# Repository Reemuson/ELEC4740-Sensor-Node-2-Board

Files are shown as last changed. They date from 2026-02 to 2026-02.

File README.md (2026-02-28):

<p align="center" width="100%">
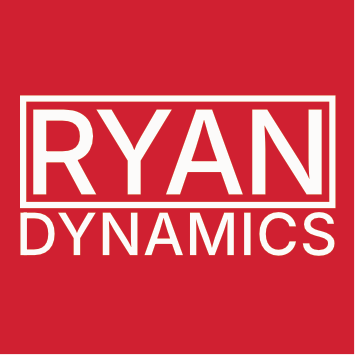
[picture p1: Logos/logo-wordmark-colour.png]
  
</p>

<h1 align="center">SN2 BREAKOUT BOARD</h1>

<p align="center" width="100%">
  <a href="https://github.com/Reemuson/ELEC4740-Sensor-Node-2-Board/actions/workflows/ci.yaml">
    
  </a>
</p>

<p align="center" width="100%">
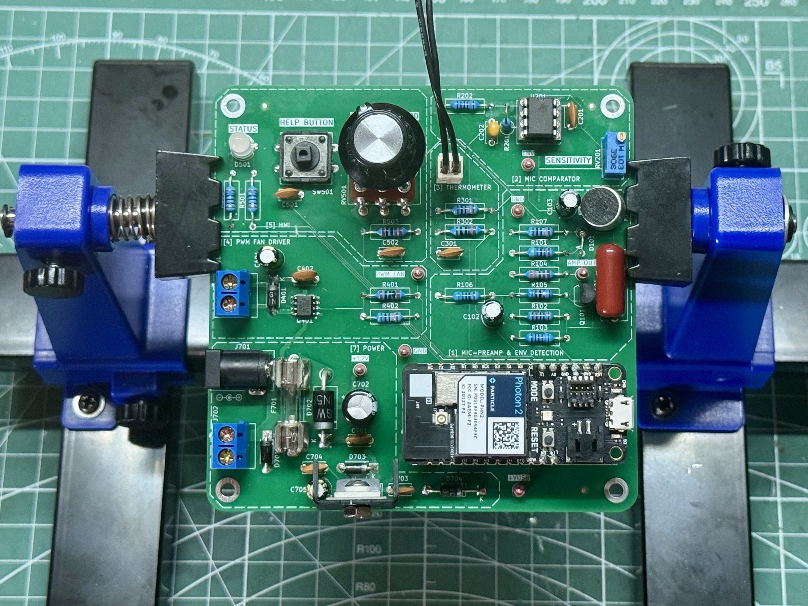
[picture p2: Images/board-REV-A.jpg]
    
</p>

***

<p align="center">
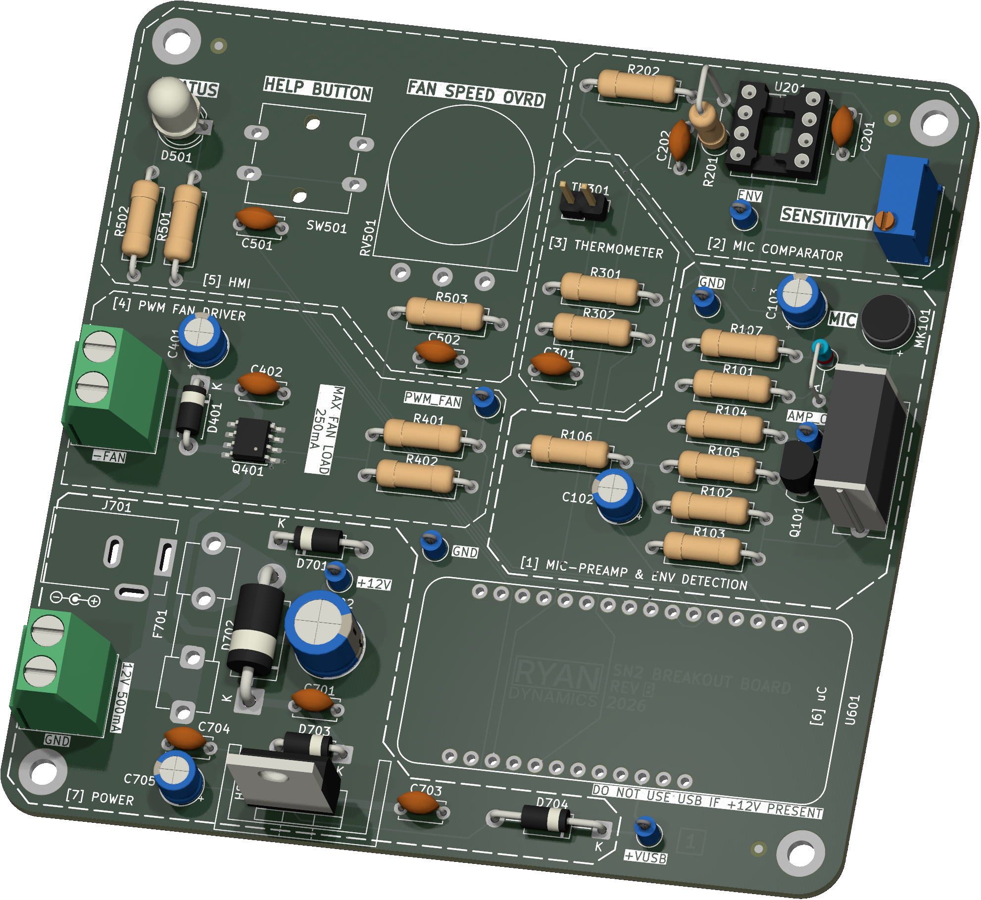
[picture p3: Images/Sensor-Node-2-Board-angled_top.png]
3D Top Angled
  
&nbsp; &nbsp; &nbsp; &nbsp;
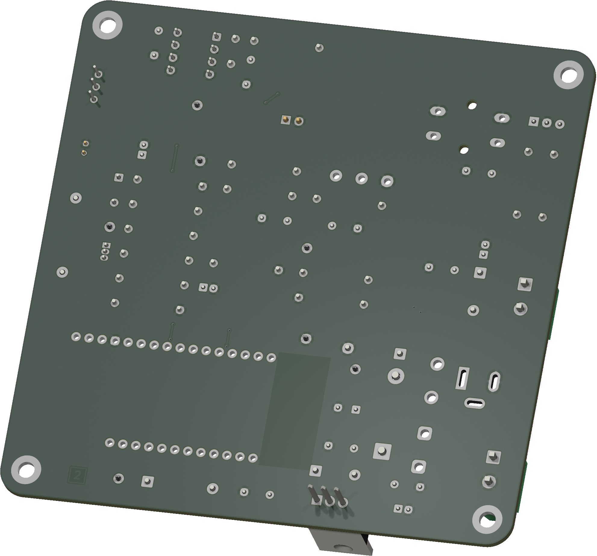
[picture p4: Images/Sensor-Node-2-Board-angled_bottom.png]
3D Bottom Angled
  
</p>

***

## SPECIFICATIONS

| Parameter | Value | 
| --- | --- |
| Dimensions | 100.0 × 100.0 mm |

***

## DIRECTORY STRUCTURE

    .
    ├─ Computations       # Misc calculations
    ├─ HTML               # HTML files for generated webpage
    ├─ Images             # Pictures and renders
    │
    ├─ kibot_resources    # External resources for KiBot
    │  ├─ colors          # Color theme for KiCad
    │  ├─ fonts           # Fonts used in the project
    │  ├─ scripts         # External scripts used with KiBot
    │  └─ templates       # Templates for KiBot generated reports
    │
    ├─ kibot_yaml         # KiBot YAML config files
    ├─ KiRI               # KiRI (PCB diff viewer) files
    │
    ├─ lib                # KiCad footprint and symbol libraries
    │  ├─ 3d_models       # Component 3D models
    │  ├─ lib_fp          # Footprint libraries
    │  └─ lib_sym         # Symbol libraries
    │
    ├─ Logos              # Logos
    │
    ├─ Manufacturing      # Assembly and fabrication documents
    │  ├─ Assembly        # Assembly documents (BoM, pos, notes)
    │  │
    │  └─ Fabrication     # Fabrication documents (ZIP, notes)
    │     ├─ Drill Tables # CSV drill tables
    │     └─ Gerbers      # Gerbers
    │
    ├─ Report             # Reports for ERC/DRC
    ├─ Schematic          # PDF of schematic
    ├─ Templates          # Title block templates
    ├─ Testing
    │  └─ Testpoints      # Testpoints tables      
    │
    └─ Variants           # Outputs for assembly variants

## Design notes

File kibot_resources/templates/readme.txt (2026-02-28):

<p align="center" width="100%">
  
</p>

<h1 align="center">${BOARD_NAME}</h1>

<p align="center" width="100%">
  <a href="${GIT_URL}/actions/workflows/ci.yaml">
    CI Badge
  </a>
</p>

<p align="center" width="100%">
    
</p>

***

<p align="center">
  3D Top Angled
&nbsp; &nbsp; &nbsp; &nbsp;
  3D Bottom Angled
</p>

***

## SPECIFICATIONS

| Parameter | Value | 
| --- | --- |
| Dimensions | ${bb_w_mm} × ${bb_h_mm} mm |

***

## DIRECTORY STRUCTURE

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

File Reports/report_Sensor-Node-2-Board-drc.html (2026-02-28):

Logo

(https://github.com/INTI-CMNB/KiBot/) | DRC report for Sensor-Node-2-Board
| PCB: Sensor-Node-2-Board Revision: 1.1.0+ (Unreleased) Date: 2026-02-28T02:42:13+0000 KiCad Version: 9.0.7 | Errors: 7 Warnings: 26 Total: 33

Violations

Type | Description | Details
items_not_allowed | Items not allowed (keepout area) | @(204.56 mm, 174.0 mm): PTH pad 1 [+12V] of D703
clearance | Clearance violation (netclass 'GND' clearance 0.2000 mm; actual 0.0000 mm) | @(225.99 mm, 151.25 mm): Via [/SCHEMATIC/GPIO_SOUND] on L1 (Sig, PWR) - L2 (Sig, GND) @(165.0 mm, 85.0 mm): Zone [GND] on L2 (Sig, GND), priority 3
hole_clearance | Hole clearance violation (board setup constraints hole clearance 0.2540 mm; actual 0.0905 mm) | @(225.99 mm, 151.25 mm): Via [/SCHEMATIC/GPIO_SOUND] on L1 (Sig, PWR) - L2 (Sig, GND) @(165.0 mm, 85.0 mm): Zone [GND] on L2 (Sig, GND), priority 3
clearance | Clearance violation (rule 'Minimum Trace Width and Spacing (outer layer)' clearance 0.2000 mm; actual 0.1405 mm) | @(225.99 mm, 148.01 mm): Track [/SCHEMATIC/GPIO_SOUND] on L2 (Sig, GND), length 3.2400 mm @(165.0 mm, 85.0 mm): Zone [GND] on L2 (Sig, GND), priority 3
clearance | Clearance violation (rule 'Minimum Trace Width and Spacing (outer layer)' clearance 0.2000 mm; actual 0.1505 mm) | @(226.0 mm, 151.0 mm): Track [/SCHEMATIC/GPIO_SOUND] on L2 (Sig, GND), length 0.2400 mm @(165.0 mm, 85.0 mm): Zone [GND] on L2 (Sig, GND), priority 3
clearance | Clearance violation (rule 'Minimum Trace Width and Spacing (outer layer)' clearance 0.2000 mm; actual 0.1405 mm) | @(226.0 mm, 151.24 mm): Track [/SCHEMATIC/GPIO_SOUND] on L2 (Sig, GND), length 0.0141 mm @(165.0 mm, 85.0 mm): Zone [GND] on L2 (Sig, GND), priority 3
lib_footprint_mismatch | Footprint 'C_Disc_D5.0mm_W2.5mm_P5.00mm' does not match copy in library 'Capacitor_THT'. | @(218.7 mm, 125.0 mm): Footprint C301
lib_footprint_mismatch | Footprint 'C_Disc_D5.0mm_W2.5mm_P5.00mm' does not match copy in library 'Capacitor_THT'. | @(205.0 mm, 125.0 mm): Footprint C502
lib_footprint_mismatch | Footprint 'C_Disc_D5.0mm_W2.5mm_P5.00mm' does not match copy in library 'Capacitor_THT'. | @(217.5 mm, 179.75 mm): Footprint C703
lib_footprint_mismatch | Footprint 'C_Disc_D5.0mm_W2.5mm_P5.00mm' does not match copy in library 'Capacitor_THT'. | @(184.0 mm, 175.0 mm): Footprint C704
lib_footprint_mismatch | Footprint 'D_DO-201AD_P15.24mm_Horizontal' does not match copy in library 'Diode_THT'. | @(192.5 mm, 168.74 mm): Footprint D702
lib_footprint_mismatch | Footprint 'PHOTON2' does not match copy in library 'Photon2'. | @(210.67 mm, 151.23 mm): Footprint U601
lib_footprint_mismatch | Footprint 'Potentiometer_Bourns_3296W_Vertical' does not match copy in library 'Potentiometer_THT'. | @(260.0 mm, 105.04 mm): Footprint RV201
lib_footprint_mismatch | Footprint 'CP_Radial_D5.0mm_P2.00mm' does not match copy in library 'Capacitor_THT'. | @(187.455112 mm, 179.75 mm): Footprint C705
lib_footprint_mismatch | Footprint 'Potentiometer_Omeg_PC16BU_Vertical' does not match copy in library 'Potentiometer_THT'. | @(211.0 mm, 115.0 mm): Footprint RV501
lib_footprint_mismatch | Footprint 'SW_SPST_Omron_B3F-40xx' does not match copy in library 'Button_Switch_THT'. | @(193.75 mm, 105.0 mm): Footprint SW501
lib_footprint_mismatch | Footprint 'TerminalBlock_Phoenix_MKDS-1,5-2_1x02_P5.00mm_Horizontal' does not match copy in library 'TerminalBlock_Phoenix'. | @(171.0 mm, 132.5 mm): Footprint J401
lib_footprint_mismatch | Footprint 'C_Disc_D5.0mm_W2.5mm_P5.00mm' does not match copy in library 'Capacitor_THT'. | @(203.0 mm, 168.74 mm): Footprint C701
lib_footprint_mismatch | Footprint 'SO-8_3.9x4.9mm_P1.27mm' does not match copy in library 'Package_SO'. | @(187.5 mm, 137.5 mm): Footprint Q401
lib_footprint_mismatch | Footprint 'CP_Radial_D5.0mm_P2.00mm' does not match copy in library 'Capacitor_THT'. | @(232.5 mm, 140.0 mm): Footprint C102
lib_footprint_mismatch | Footprint 'LED_D5.0mm-3' does not match copy in library 'LED_THT'. | @(175.04 mm, 100.0 mm): Footprint D501
lib_footprint_mismatch | Footprint 'CP_Radial_D5.0mm_P2.00mm' does not match copy in library 'Capacitor_THT'. | @(180.0 mm, 127.5 mm): Footprint C401
lib_footprint_mismatch | Footprint 'D_DO-41_SOD81_P12.70mm_Horizontal' does not match copy in library 'Diode_THT'. | @(236.35 mm, 179.75 mm): Footprint D704
lib_footprint_mismatch | Footprint 'C_Disc_D5.0mm_W2.5mm_P5.00mm' does not match copy in library 'Capacitor_THT'. | @(185.0 mm, 131.19 mm): Footprint C402
lib_footprint_mismatch | Footprint 'C_Disc_D5.0mm_W2.5mm_P5.00mm' does not match copy in library 'Capacitor_THT'. | @(250.0 mm, 90.0 mm): Footprint C201
lib_footprint_mismatch | Footprint 'DIP-8_W7.62mm_Socket' does not match copy in library 'Package_DIP'. | @(238.69 mm, 90.0 mm): Footprint U201
lib_footprint_mismatch | Footprint 'TO-220-3_Vertical' does not match copy in library 'Package_TO_SOT_THT'. | @(203.29 mm, 179.75 mm): Footprint U701
lib_footprint_mismatch | Footprint 'PinHeader_1x02_P2.54mm_Vertical' does not match copy in library 'Connector_PinHeader_2.54mm'. | @(222.54 mm, 105.0 mm): Footprint TH301
lib_footprint_mismatch | Footprint 'C_Disc_D5.0mm_W2.5mm_P5.00mm' does not match copy in library 'Capacitor_THT'. | @(231.35 mm, 93.81 mm): Footprint C202
lib_footprint_mismatch | Footprint 'CP_Radial_D5.0mm_P2.00mm' does not match copy in library 'Capacitor_THT'. | @(248.85 mm, 115.0 mm): Footprint C103
lib_footprint_mismatch | Footprint 'TerminalBlock_Phoenix_MKDS-1,5-2_1x02_P5.00mm_Horizontal' does not match copy in library 'TerminalBlock_Phoenix'. | @(171.0 mm, 167.5 mm): Footprint J702
lib_footprint_mismatch | Footprint 'C_Disc_D5.0mm_W2.5mm_P5.00mm' does not match copy in library 'Capacitor_THT'. | @(181.25 mm, 111.25 mm): Footprint C501

Unconnected items

Type | Description | Details
unconnected_items | Missing connection between items | @(184.25 mm, 148.75 mm): Zone [/SCHEMATIC/+12V_FUSED] on L1 (Sig, PWR), priority 2 @(192.5 mm, 149.0 mm): PTH pad 1 [/SCHEMATIC/+12V_FUSED] of D701

Generated by KiBot (https://github.com/INTI-CMNB/KiBot/) v1.8.6

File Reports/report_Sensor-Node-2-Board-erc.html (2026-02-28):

Logo

(https://github.com/INTI-CMNB/KiBot/) | ERC report for Sensor-Node-2-Board
| Schematic: Sensor-Node-2-Board Revision: 1.1.0+ (Unreleased) Date: 2026-02-28T02:42:11+0000 KiCad Version: 9.0.7 | Errors: 0 Warnings: 12 Total: 12

Sheet / (Sensor-Node-2-Board.kicad_sch)

Type | Description | Details
lib_symbol_mismatch | Symbol 'BC549' doesn't match copy in library 'Transistor_BJT' | @(1.3335 mm, 0.6985 mm): Symbol Q101 [BC549]
footprint_link_issues | The current configuration does not include the footprint library 'RD-Testpoints'. | @(1.4605 mm, 0.5461 mm): Symbol TP101 [TestPoint]
lib_symbol_mismatch | Symbol 'Thermistor_NTC' doesn't match copy in library 'Device' | @(0.762 mm, 1.4097 mm): Symbol TH301 [Thermistor_NTC]
footprint_link_issues | The current configuration does not include the footprint library 'RD-Testpoints'. | @(1.3716 mm, 1.27 mm): Symbol TP401 [TestPoint]
footprint_link_issues | The current configuration does not include the footprint library 'RD-Testpoints'. | @(1.3716 mm, 1.778 mm): Symbol TP901 [TestPoint]
footprint_link_issues | The current configuration does not include the footprint library 'RD-Testpoints'. | @(1.3716 mm, 1.9558 mm): Symbol TP902 [TestPoint]
footprint_link_issues | The current configuration does not include the footprint library 'RD-Testpoints'. | @(2.5146 mm, 0.5461 mm): Symbol TP201 [TestPoint]
footprint_link_issues | The current configuration does not include the footprint library 'RD-Symbols-Silkscreen'. | @(1.7526 mm, 1.9431 mm): Symbol ID901 [BOARD_STACKUP_MARKER]
lib_symbol_issues | The current configuration does not include the symbol library 'Ryan-Dynamics' | @(1.7526 mm, 1.9431 mm): Symbol ID901 [BOARD_STACKUP_MARKER]
footprint_link_issues | The current configuration does not include the footprint library 'RD-Testpoints'. | @(2.54 mm, 1.8161 mm): Symbol TP702 [TestPoint]
footprint_link_issues | The current configuration does not include the footprint library 'RD-Heatsinks'. | @(2.9845 mm, 1.7653 mm): Symbol HS701 [Heatsink]
footprint_link_issues | The current configuration does not include the footprint library 'RD-Testpoints'. | @(3.2004 mm, 1.778 mm): Symbol TP701 [TestPoint]

Generated by KiBot (https://github.com/INTI-CMNB/KiBot/) v1.8.6

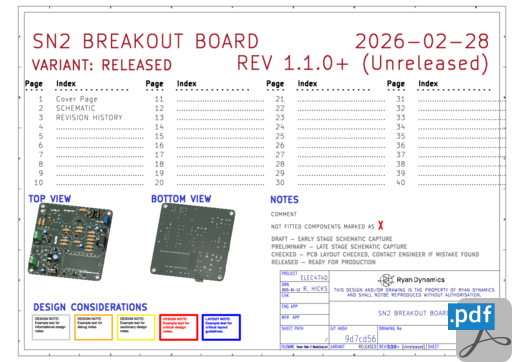
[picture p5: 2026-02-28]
HTML/images/cat_pdf_schematic_Sensor-Node-2-Board-schematic.png

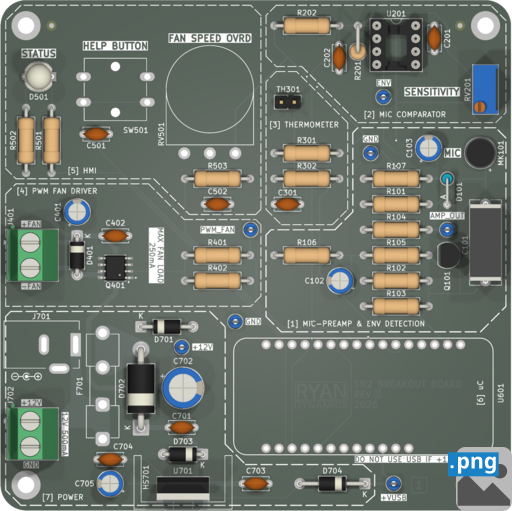
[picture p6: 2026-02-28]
HTML/images/cat_png_3d_viewer_top_Sensor-Node-2-Board-top.png

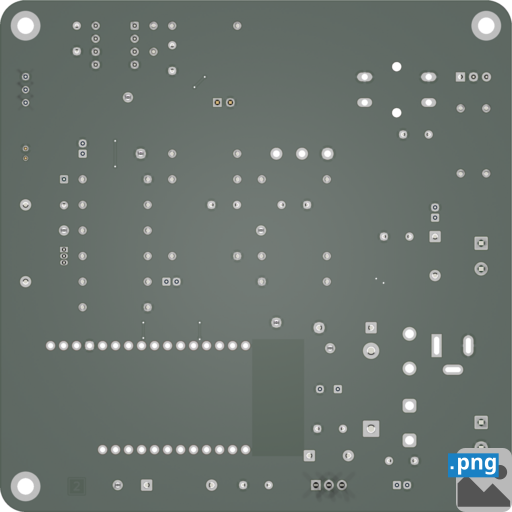
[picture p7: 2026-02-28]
HTML/images/cat_png_3d_viewer_bottom_Sensor-Node-2-Board-bottom.png

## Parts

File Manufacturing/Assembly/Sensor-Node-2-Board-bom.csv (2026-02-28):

Row | Quantity Per PCB | References | Value | Datasheet | Footprint | Description | Tolerance | Voltage | Manufacturer | MPN | Supplier | SPN | Notes
1 | 8 | C201 C301 C402 C501 C502 C701 C703 C704 | 100n | ~ | C_Disc_D5.0mm_W2.5mm_P5.00mm | CAP CER Y5U 100N 50V 20% P=5MM | 20% | 50V |  |  | Jaycar Electronics | RC5360
2 | 2 | C101 C202 | 1u | ~ | C_Rect_L16.5mm_W6.0mm_P15.00mm_MKT | CAP GRN 1U 100V P=11MM CAP MONO 1U 50V |  | 100V 50V |  |  | Jaycar Electronics | RG5170
3 | 2 | C102 C103 | 3.3u | ~ | CP_Radial_D5.0mm_P2.00mm | CAP LL CD81 RB 3U3 50V P=2MM 5X11MM | 10% | 50V |  |  | Jaycar Electronics | RL6422
4 | 2 | C401 C705 | 10u | ~ | CP_Radial_D5.0mm_P2.00mm | Polarized capacitor |  | 25V
5 | 1 | C702 | 47u | ~ | CP_Radial_D8.0mm_P3.50mm | Polarized capacitor |  | 25V
6 | 1 | D703 | 1N4004 | http://www.vishay.com/docs/88503/1n4001.pdf | D_DO-41_SOD81_P7.62mm_Horizontal | 400V 1A General Purpose Rectifier Diode, DO-41
7 | 1 | D101 | 1N4148 | https://assets.nexperia.com/documents/data-sheet/1N4148_1N4448.pdf | D_DO-35_SOD27_P5.08mm_Vertical_AnodeUp | DIODE 1N4148 FAST 100V 250MA DO41 |  |  |  |  | Jaycar Electronics
8 | 2 | D401 D704 | 1N5819 | http://www.vishay.com/docs/88525/1n5817.pdf | D_DO-41_SOD81_P7.62mm_Horizontal | DIODE 1N5819 SCHOTTKY 40V 1A DO41 |  |  |  |  | Jaycar Electronics | ZR1020
9 | 1 | D702 | 1N5822 | http://www.vishay.com/docs/88526/1n5820.pdf | D_DO-201AD_P15.24mm_Horizontal | DIODE 1N5822 SCHOTTKY 40V 3A DO41 |  |  |  |  | Jaycar Electronics | ZR1023
10 | 1 | D501 | LED_STATUS | ~ | LED_D5.0mm-3 | LED 5MM DIF BICOL COM CATH ORG/GRN 70/80 |  |  |  |  | Jaycar Electronics | ZD0252
11 | 1 | D701 | P4KE16 | ~ | D_DO-41_SOD81_P10.16mm_Horizontal | DIODE TVS UNIDIRECTIONAL
12 | 1 | F701 | 500mA M205 | ~ | Fuseholder_Clip-5x20mm_Eaton_1A5601-01_Inline_P20.80x6.76mm_D1.70mm_Horizontal | Fuse
13 | 1 | HS701 | Heatsink | ~ | Heatsink_6073B_19x9.5mm | Heatsink
14 | 3 | J401 J701 J702 | EBWA-02-B | ~ | TerminalBlock_Phoenix_MKDS-1,5-2_1x02_P5.00mm_Horizontal | TERMINAL PCB SCREW 2WAY BLU P=5MM SKT PCB DC SPST SWITCHED 2.1MM |  |  |  |  | Jaycar Electronics | HM3412
15 | 1 | MK101 | MIC | ~ | POM-2244P-C3310-2-R | MIC PCB 2PIN 1.5V D10XH6.5MM |  |  |  |  | Jaycar Electronics | AM4011
16 | 1 | Q101 | BC549 | https://www.onsemi.com/pub/Collateral/BC550-D.pdf | TO-92_Inline | TRAN BC540 NPN 30V 100MA TO92
17 | 1 | Q401 | Si4944DY | https://www.digikey.com.au/en/htmldatasheets/production/831318/0/0/2/si4944dy | SO-8_3.9x4.9mm_P1.27mm | SMD MOSFET SI4944DY DUAL N-CH 30V SOIC8 |  |  |  |  | Jaycar Electronics | ZK8821
18 | 1 | R105 | 62 | ~ | R_Axial_DIN0309_L9.0mm_D3.2mm_P12.70mm_Horizontal | RES 0.5W CARB 62R | 1%
19 | 1 | R401 | 100 | ~ | R_Axial_DIN0309_L9.0mm_D3.2mm_P12.70mm_Horizontal | RES 0.5W CARB 100R | 1%
20 | 2 | R501 R502 | 120 | ~ | R_Axial_DIN0309_L9.0mm_D3.2mm_P12.70mm_Horizontal | RES 0.5W CARB 120R | 1%
21 | 1 | R106 | 560 | ~ | R_Axial_DIN0309_L9.0mm_D3.2mm_P12.70mm_Horizontal | RES 0.5W CARB 560R | 1%
22 | 2 | R302 R503 | 1k | ~ | R_Axial_DIN0309_L9.0mm_D3.2mm_P12.70mm_Horizontal | RES 0.5W CARB 1K | 1%
23 | 1 | R104 | 3.3k | ~ | R_Axial_DIN0309_L9.0mm_D3.2mm_P12.70mm_Horizontal | RES 0.5W CARB 3.3K | 1%
24 | 1 | R101 | 4.7k | ~ | R_Axial_DIN0309_L9.0mm_D3.2mm_P12.70mm_Horizontal | RES 0.5W CARB 4.7K | 1%
25 | 4 | R103 R202 RV201 RV501 | 10k | ~ | R_Axial_DIN0309_L9.0mm_D3.2mm_P12.70mm_Horizontal | RES 0.5W CARB 10K TRIMPOT 25TURN 10K TOP ADJ POT PCB LIN SG 16MM B10K STD IMP SHAFT | 1% |  |  |  | Jaycar Electronics | RT4650 RP7510
26 | 1 | R102 | 22k | ~ | R_Axial_DIN0309_L9.0mm_D3.2mm_P12.70mm_Horizontal | RES 0.5W CARB 22K | 1%
27 | 3 | R107 R301 R402 | 100k | ~ | R_Axial_DIN0309_L9.0mm_D3.2mm_P12.70mm_Horizontal | RES 0.5W CARB 100K | 1%
28 | 1 | R201 | 1Meg | ~ | R_Axial_DIN0309_L9.0mm_D3.2mm_P5.08mm_Vertical | RES 0.5W CARB 1M | 1%
29 | 1 | SW501 | SW_HELP | ~ | SW_SPST_Omron_B3F-40xx | SWITCH PCB TACT SPST SQR STEM 11.9X11.9 |  |  |  |  | Jaycar Electronics | SP0608
30 | 1 | TH301 | NTC100K | ~ | PinHeader_1x02_P2.54mm_Vertical | THERMISTOR NTC GLASS 100KR 250DEG |  |  |  |  | Jaycar Electronics | RN3446
31 | 1 | U701 | L7805 | http://www.st.com/content/ccc/resource/technical/document/datasheet/41/4f/b3/b0/12/d4/47/88/CD00000444.pdf/files/CD00000444.pdf/jcr:content/translations/en.CD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 | TO-220-3_Vertical | VREG 7805 +5V 1A TO220 |  |  |  |  | Jaycar Electronics | ZV1505
32 | 1 | U201 | LM393 | http://www.ti.com/lit/ds/symlink/lm393.pdf | DIP-8_W7.62mm_Socket | IC LM393N LO-PWR DUAL COMPARATOR DIP8 |  |  |  |  | Jaycar Electronics | ZL3393
33 | 1 | U601 | Photon 2 | https://docs.particle.io/reference/datasheets/wi-fi/photon-2-datasheet/ | PHOTON2 | PHOTON 2 [X1]

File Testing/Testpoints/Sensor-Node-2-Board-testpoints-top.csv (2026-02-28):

Ref. | Net | X [mm] | Y [mm]
TP101 | AMP_OUT | 87.50 | 55.00
TP201 | ENV | 75.00 | 81.00
TP401 | PWM_FAN | 49.00 | 55.00
TP701 | +VUSB | 77.00 | 5.25
TP702 | +12V | 35.50 | 32.00
TP901 | GND | 72.50 | 70.00
TP902 | GND | 46.00 | 37.00

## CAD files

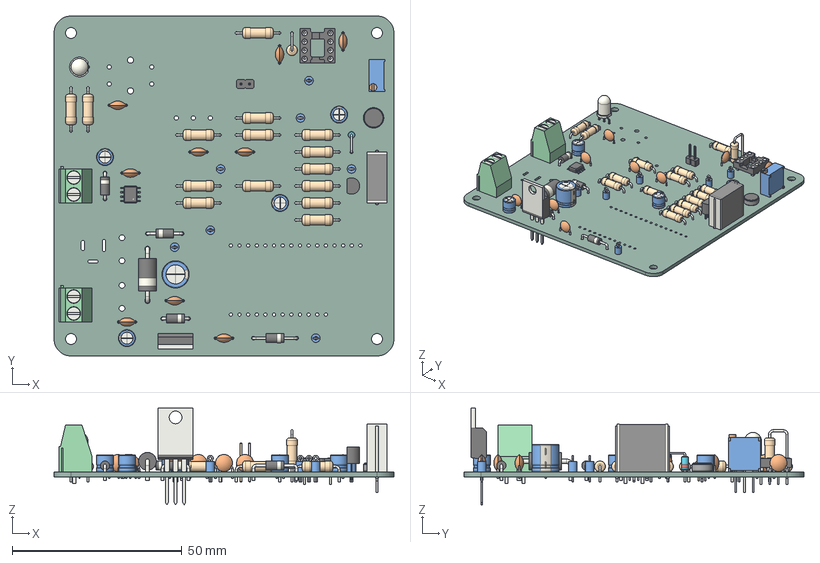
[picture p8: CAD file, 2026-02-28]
3D/Sensor-Node-2-Board.step
100.0 x 100.0 x 28.5 mm
C_Disc_D5.0mm_W2.5mm_P5.00mm x 9
D_DO-35_SOD27_P5.08mm_Vertical_AnodeUp
TestPoint_Loop_D1.80mm_Drill1.0mm_Beaded x 7
POM-2244P-C3310-2-R
CP_Radial_D8.0mm_P3.50mm
D_DO-41_SOD81_P7.62mm_Horizontal x 2
R_Axial_DIN0309_L9.0mm_D3.2mm_P12.70mm_Horizontal x 15
R_Axial_DIN0309_L9.0mm_D3.2mm_P5.08mm_Vertical
TO-92_Inline
D_DO-41_SOD81_P10.16mm_Horizontal
D_DO-201AD_P15.24mm_Horizontal
Potentiometer_Bourns_3296W_Vertical
CP_Radial_D5.0mm_P2.00mm x 4
TerminalBlock_Phoenix_MKDS-1,5-2_1x02_P5.00mm_Horizontal x 2
SO-8_3.9x4.9mm_P1.27mm
LED_D5.0mm-3
D_DO-41_SOD81_P12.70mm_Horizontal
C_Rect_L16.5mm_W6.0mm_P15.00mm_MKT
DIP-8_W7.62mm_Socket
TO-220-3_Vertical
PinHeader_1x02_P2.54mm_Vertical
kibot_6sbxkcy1_PCB

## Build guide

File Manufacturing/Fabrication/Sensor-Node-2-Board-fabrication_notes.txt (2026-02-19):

FABRICATION NOTES (UNLESS OTHERWISE SPECIFIED)

1)	FABRICATE PER IPC-6012A CLASS 2.

2)	OUTLINE DEFINED IN SEPARATE GERBER FILE WITH
	"Edge_Cuts.GBR" SUFFIX.

3)	SEE SEPARATE DRILL FILES WITH ".DRL" SUFFIX 
	FOR HOLE LOCATIONS.

4)	SURFACE FINISH: HAL SNPB

5)	SOLDERMASK ON BOTH SIDES OF THE BOARD SHALL 
	BE LPI, COLOR GREEN.

6)	SILK SCREEN LEGEND TO BE APPLIED PER LAYER 
	STACKUP USING WHITE NON-CONDUCTIVE EPOXY INK.

7)	VENDOR SHOULD FOLLOW ROHS COMPLIANT PROCESS 
	AND Pb FREE FOR MANUFACTURING

8)	PCB MATERIAL REQUIREMENTS:

	A.	FLAMMABILITY RATING MUST MEET OR EXCEED 
		UL94V-0 REQUIREMENTS.
	B.	Tg 170 C OR EQUIVALENT.
	C.	EQUIVALENT MATERIAL SHALL BE RoHS COMPLIANT, 
		HALOGEN FREE AND APPROVED BY RYAN DYNAMICS.

9)	DESIGN GEOMETRY MINIMUM FEATURE SIZES:

	BOARD SIZE			100.000 × 100.000 mm
	BOARD THICKNESS		1.600 mm
	TRACE WIDTH			0.200 mm
	TRACE TO TRACE		0.200 mm
	MIN. HOLE (PTH)		0.300 mm
	MIN. HOLE (NPTH)	1.800 mm
	ANNULAR RING		0.150 mm
	COPPER TO HOLE		0.254 mm
	COPPER TO EDGE		0.250 mm
	HOLE TO HOLE		0.254 mm

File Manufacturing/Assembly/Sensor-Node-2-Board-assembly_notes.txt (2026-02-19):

ASSEMBLY NOTES (UNLESS OTHERWISE SPECIFIED)

1)	DO NOT POPULATE PARTS ARE MARKED WITH A RED CROSS.

2)	DO NOT POPULATE PARTS ARE NOT PRESENT IN THE BOM.

3)	IF CONFLICTING INFORMATION IS FOUND BETWEEN THE ASSEMBLY
	FILE AND BOM, BOM SHOULD BE USED AS THE MAIN SOURCE.

4)	CONFORMAL COATING IS NOT REQUIRED.

5)	DOT IDENTIFIES PIN #1 LOCATION AND DEVICE ORIENTATION
	WHEN VIEWED FROM THE TOP.

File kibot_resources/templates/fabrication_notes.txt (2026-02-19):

FABRICATION NOTES (UNLESS OTHERWISE SPECIFIED)

1)	FABRICATE PER IPC-6012A CLASS 2.

2)	OUTLINE DEFINED IN SEPARATE GERBER FILE WITH
	"Edge_Cuts.GBR" SUFFIX.

3)	SEE SEPARATE DRILL FILES WITH ".DRL" SUFFIX 
	FOR HOLE LOCATIONS.

4)	SURFACE FINISH: ${pcb_finish_cap}

5)	SOLDERMASK ON BOTH SIDES OF THE BOARD SHALL 
	BE LPI, COLOR ${solder_mask_color_text_cap}.

6)	SILK SCREEN LEGEND TO BE APPLIED PER LAYER 
	STACKUP USING ${silk_screen_color_text_cap} NON-CONDUCTIVE EPOXY INK.

7)	VENDOR SHOULD FOLLOW ROHS COMPLIANT PROCESS 
	AND Pb FREE FOR MANUFACTURING

8)	PCB MATERIAL REQUIREMENTS:

	A.	FLAMMABILITY RATING MUST MEET OR EXCEED 
		UL94V-0 REQUIREMENTS.
	B.	Tg 170 C OR EQUIVALENT.
	C.	EQUIVALENT MATERIAL SHALL BE RoHS COMPLIANT, 
		HALOGEN FREE AND APPROVED BY ${COMPANY_cap}.

9)	DESIGN GEOMETRY MINIMUM FEATURE SIZES:

	BOARD SIZE			${bb_w_mm} × ${bb_h_mm} mm
	BOARD THICKNESS		${thickness_mm} mm
	TRACE WIDTH			${track_mm} mm
	TRACE TO TRACE		${clearance_mm} mm
	MIN. HOLE (PTH)		${drill_pth_real_mm} mm
	MIN. HOLE (NPTH)	${drill_npth_real_mm} mm
	ANNULAR RING		${oar_mm} mm
	COPPER TO HOLE		${c2h_mm} mm
	COPPER TO EDGE		${c2e_mm} mm
	HOLE TO HOLE		${h2h_mm} mm
#?stackup and impedance_controlled

#?stackup and impedance_controlled
10)	REFER TO IMPEDANCE TABLE FOR IMPEDANCE CONTROL REQUIREMENTS.
#?stackup and impedance_controlled

#?stackup and impedance_controlled
11)	CONFIRM SPACE WIDTHS AND SPACINGS.

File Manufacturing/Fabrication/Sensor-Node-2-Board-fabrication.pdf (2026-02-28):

# TOP FABRICATION (SCALE 1:1)

# SN2 BREAKOUT BOARD FABRICATION DOCUMENT

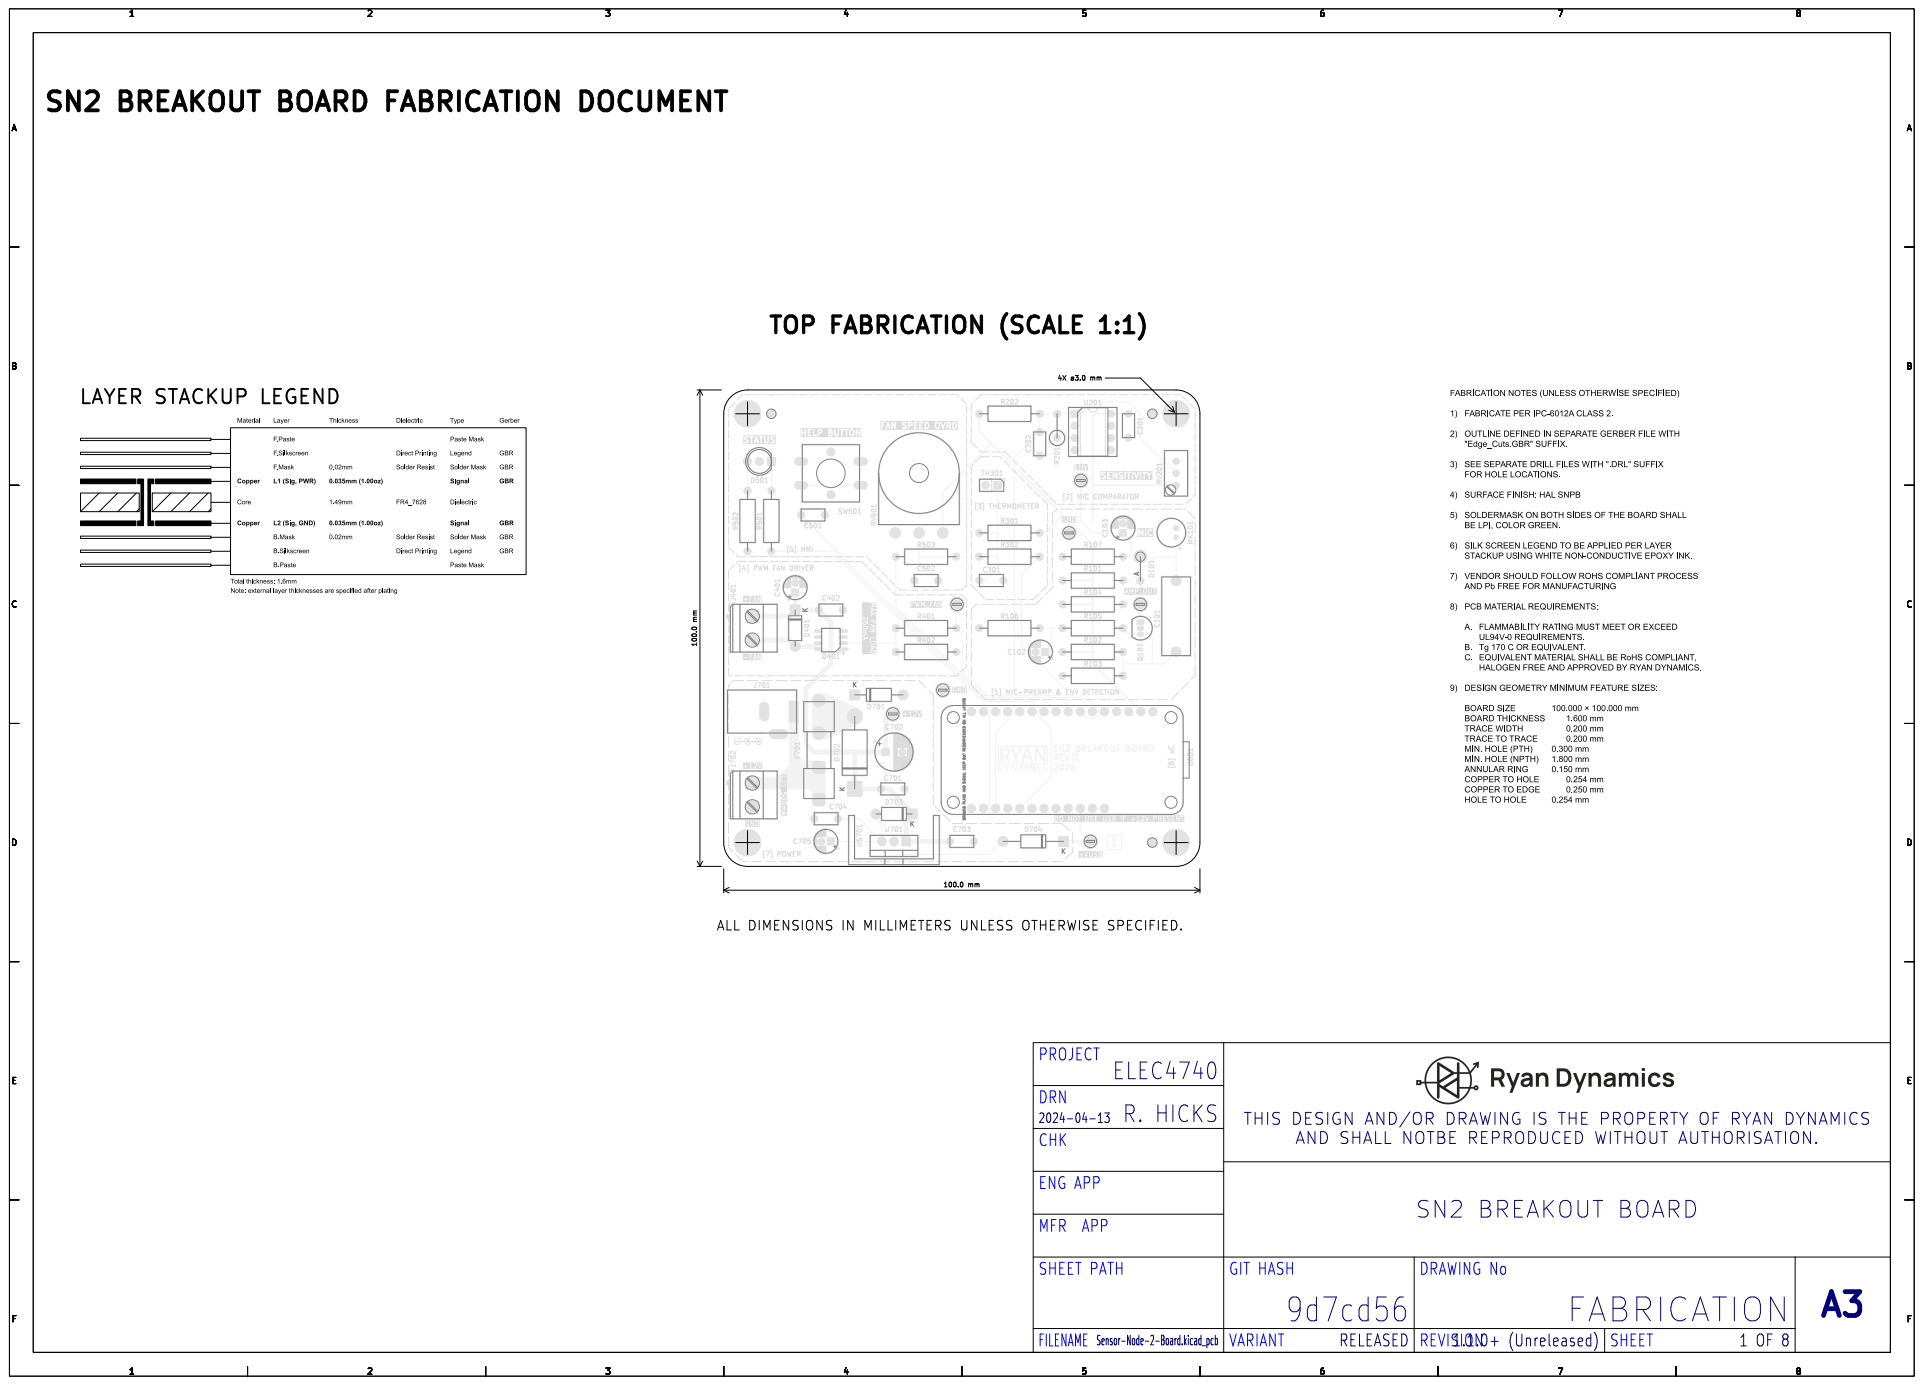
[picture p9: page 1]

[1] MIC-PREAMP & ENV DETECTION

GROUND PLANE AND SIGNAL KEEP OUT RECOMMENDED ON ALL LAYERS

ALL DIMENSIONS IN MILLIMETERS UNLESS OTHERWISE SPECIFIED.

DRN
THIS DESIGN AND/OR DRAWING IS THE PROPERTY OF RYAN DYNAMICSAND SHALL NOTBE REPRODUCED WITHOUT AUTHORISATION.
CHK

BOTTOM | FABRICATION | (SCALE | 1:1)
SN2 BREAKOUT | BOARD FABRICATION | DOCUMENT

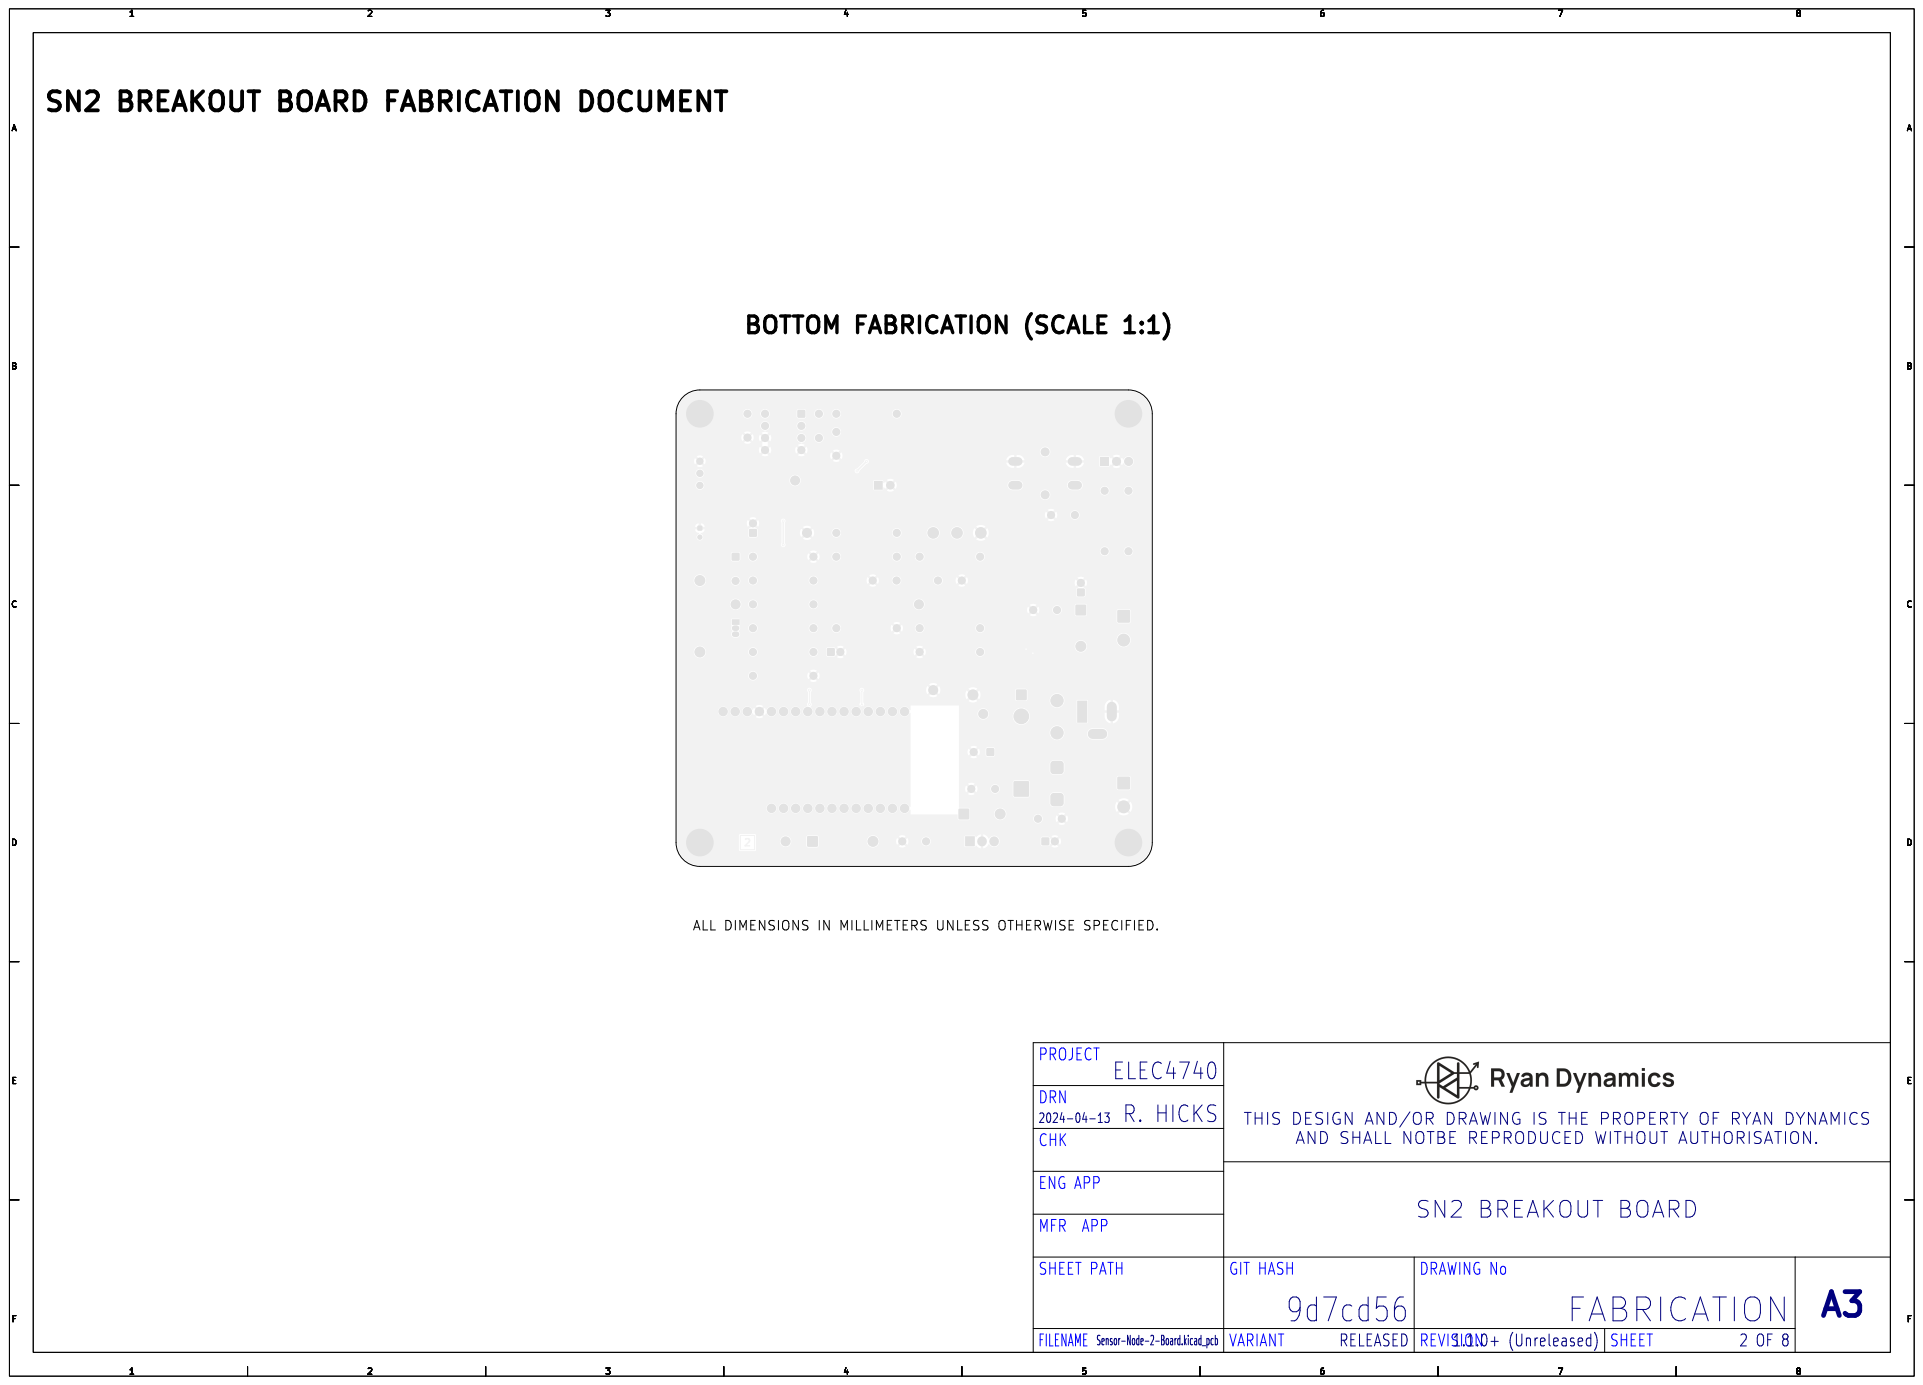
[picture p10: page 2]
DRAWING No; ELEC4740; PROJECT; BREAKOUT; BOARD; ENG APP; 2024-04-13 CHK; GIT; HASH; SHEET; PATH; MFR; APP; DRN; R. HICKS; THIS DESIGN AND/OR; DRAWING IS THE PROPERTY OF RYAN DYNAMICSAND SHALL NOTBE REPRODUCED WITHOUT AUTHORISATION.; ALL; DIMENSIONS; MILLIMETERS; UNLESS OTHERWISE; SPECIFIED.

DRILL | DRAWING L1 - L2 (SCALE | 1:1)
SN2 BREAKOUT | BOARD FABRICATION | DOCUMENT

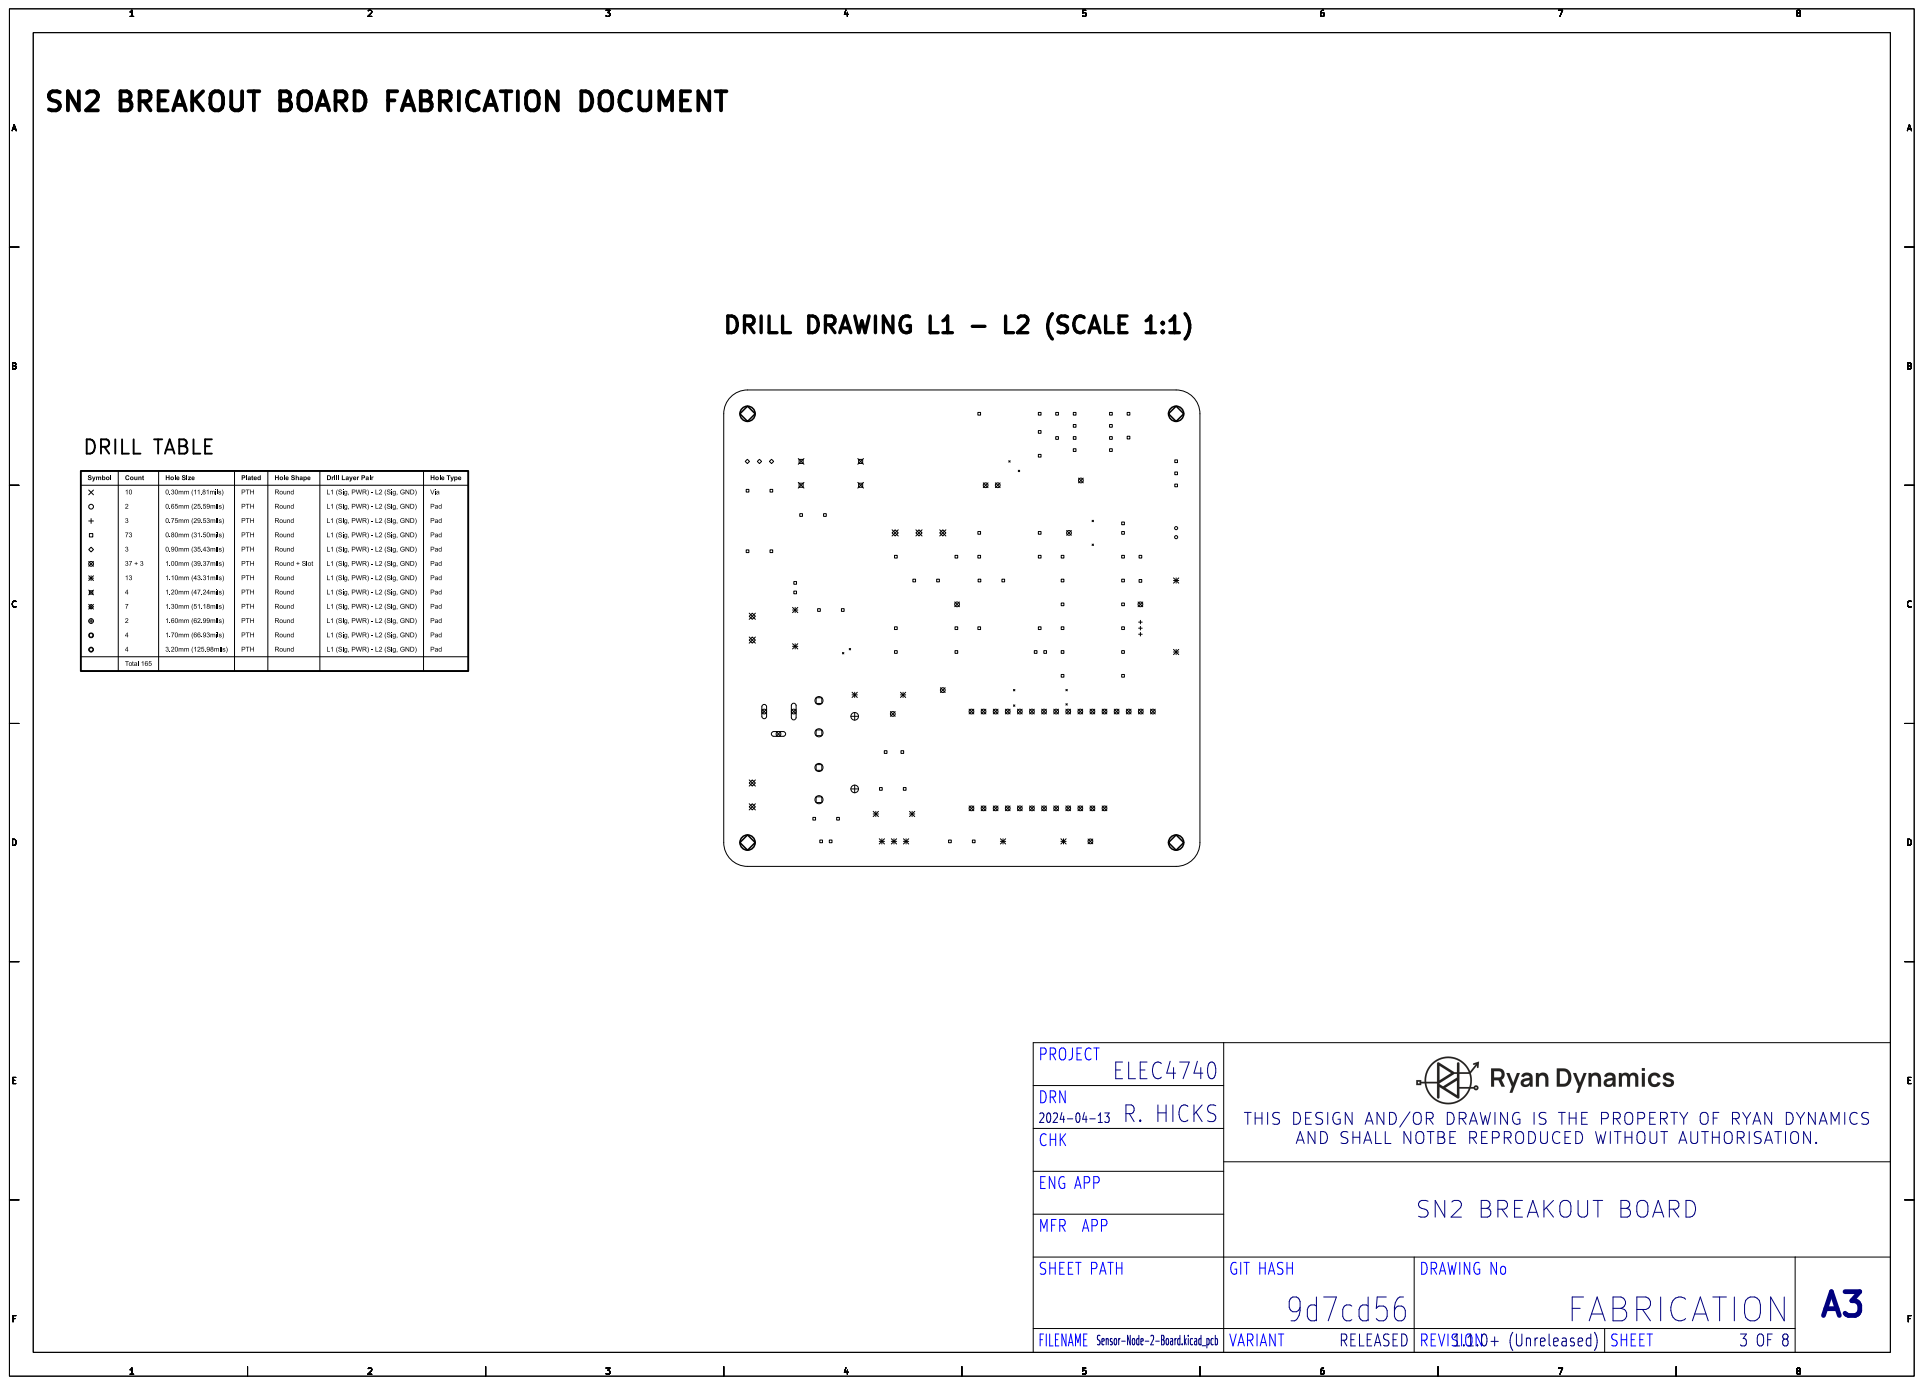
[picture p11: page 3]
DRAWING No; ELEC4740; PROJECT; BREAKOUT; BOARD; ENG APP; GIT; HASH; SHEET; PATH; MFR; APP; R. HICKS; DRILL TABLE

DRN
THIS DESIGN AND/OR DRAWING IS THE PROPERTY OF RYAN DYNAMICSAND SHALL NOTBE REPRODUCED WITHOUT AUTHORISATION.
CHK

DRILL | DRAWING L1 - L2 (SCALE | 1:1)
SN2 BREAKOUT | BOARD FABRICATION | DOCUMENT

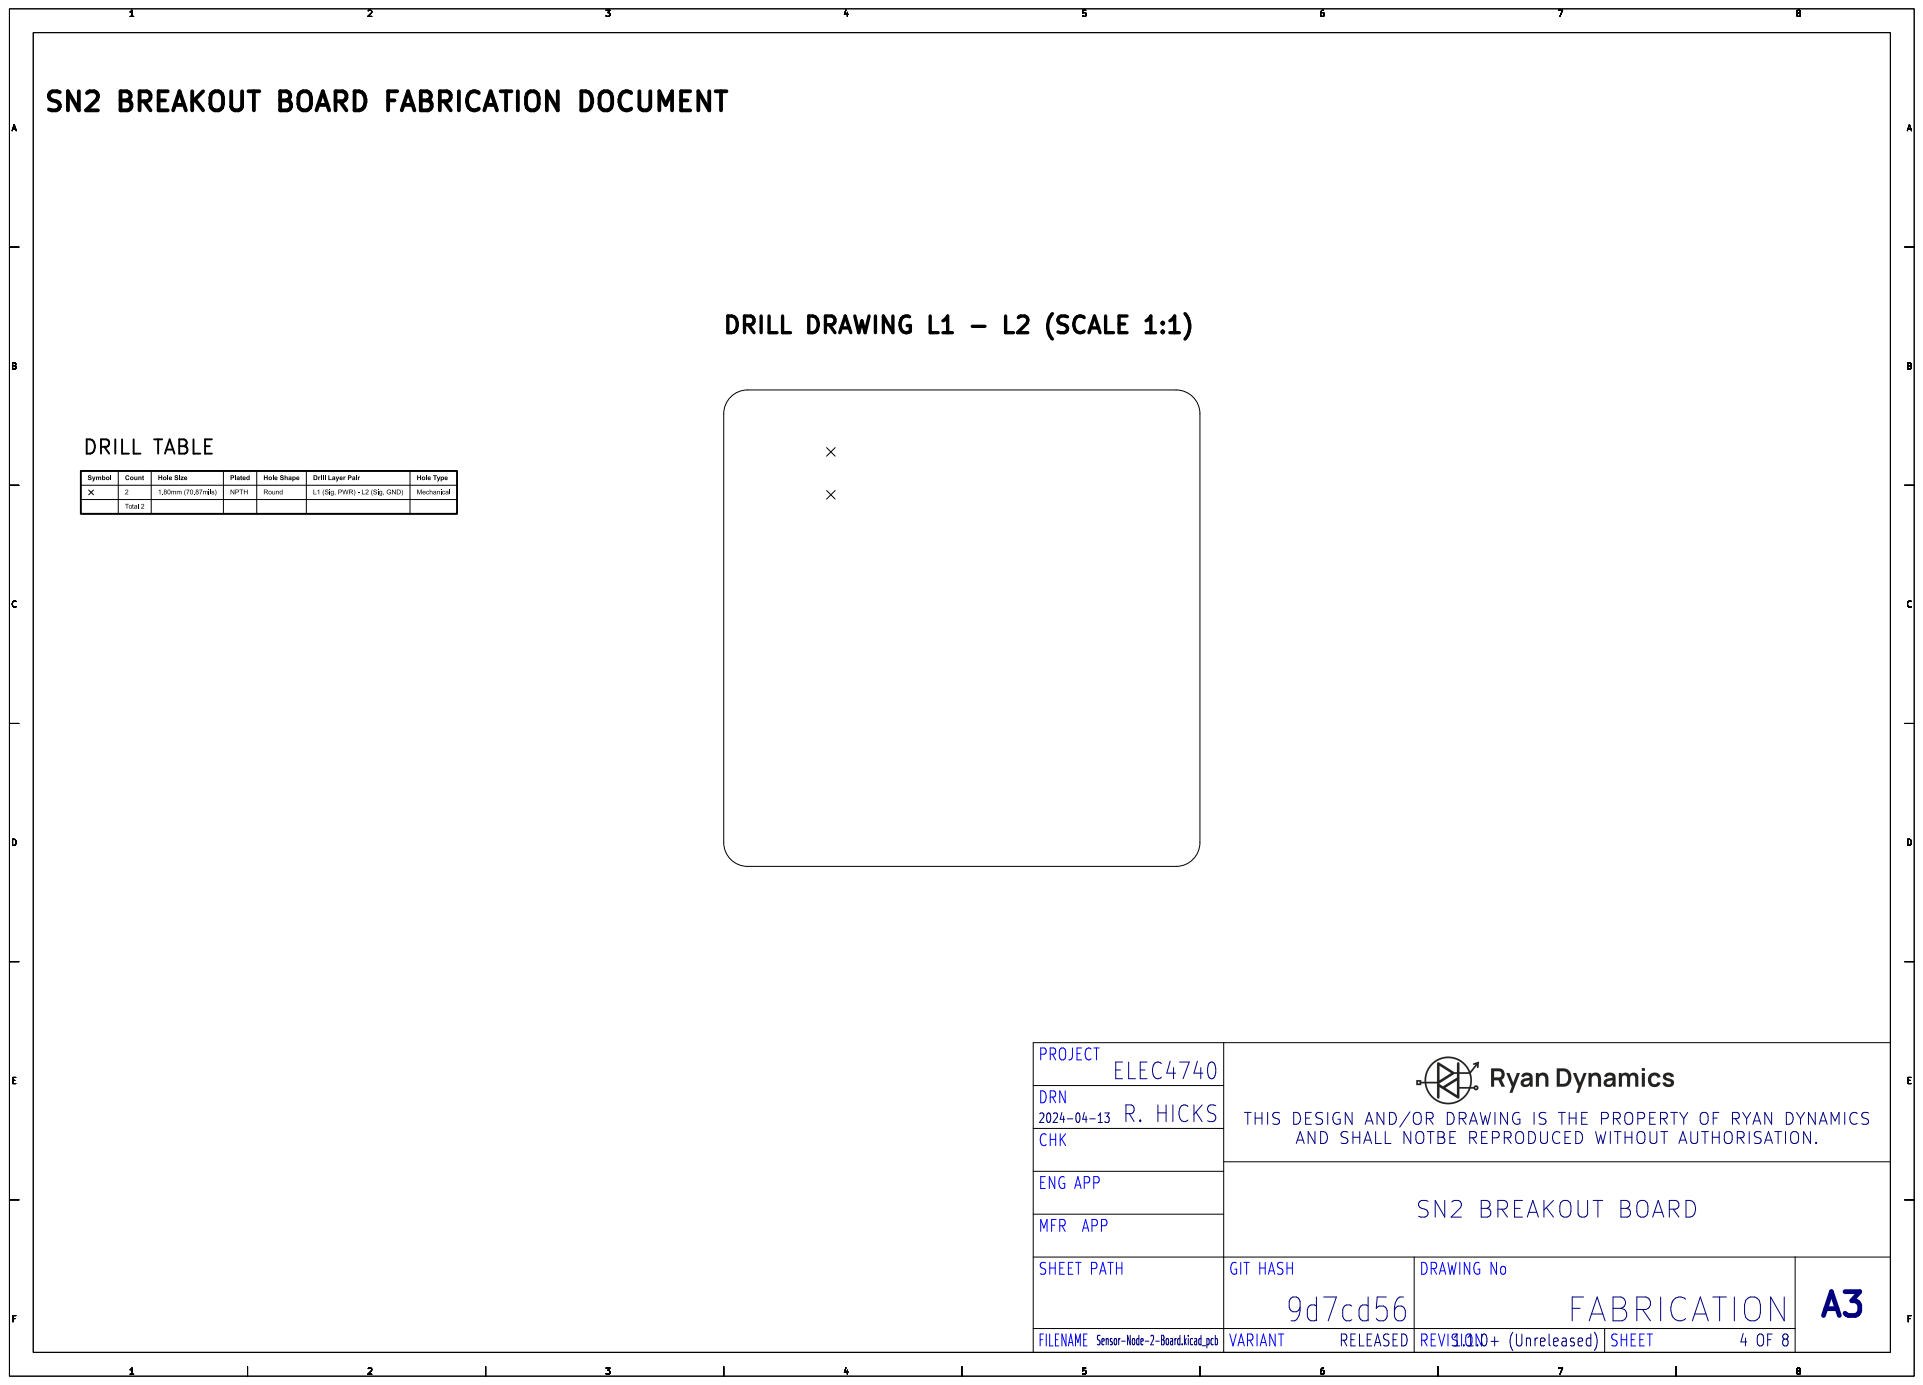
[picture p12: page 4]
DRAWING No; ELEC4740; PROJECT; BREAKOUT; BOARD; ENG APP; 2024-04-13 CHK; GIT; HASH; SHEET; PATH; MFR; APP; DRN; R. HICKS; THIS DESIGN AND/OR; DRAWING IS THE PROPERTY OF RYAN DYNAMICSAND SHALL NOTBE REPRODUCED WITHOUT AUTHORISATION.; DRILL TABLE

# TOP TEST POINTS (SCALE 1:1)

# SN2 BREAKOUT BOARD FABRICATION DOCUMENT

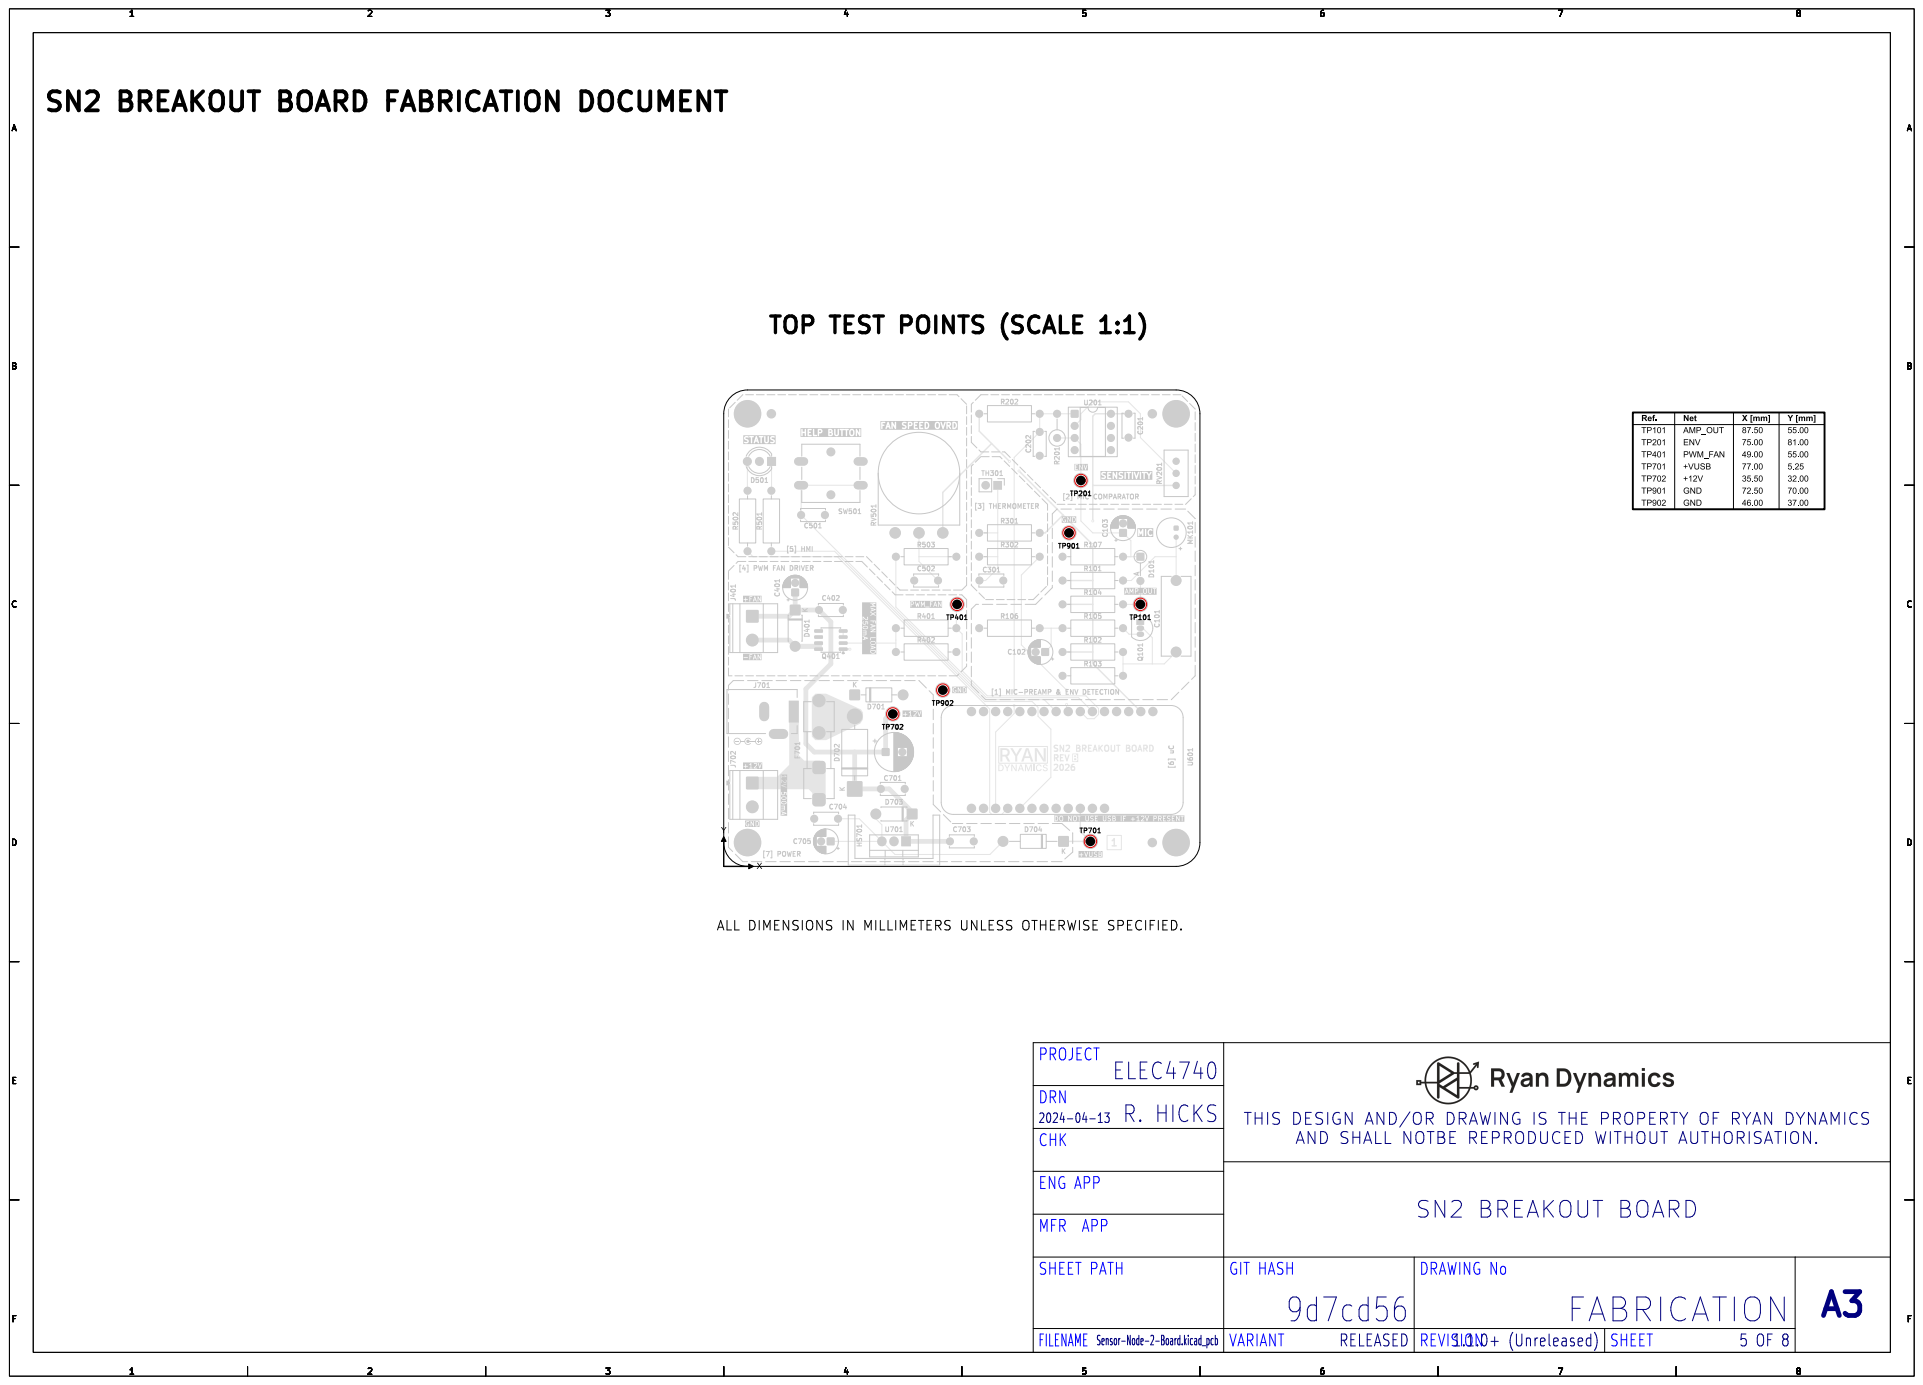
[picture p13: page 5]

[1] MIC-PREAMP & ENV DETECTION

DRN
THIS DESIGN AND/OR DRAWING IS THE PROPERTY OF RYAN DYNAMICSAND SHALL NOTBE REPRODUCED WITHOUT AUTHORISATION.
CHK

BOTTOM | TEST | POINTS (SCALE | 1:1)
SN2 BREAKOUT | BOARD FABRICATION | DOCUMENT

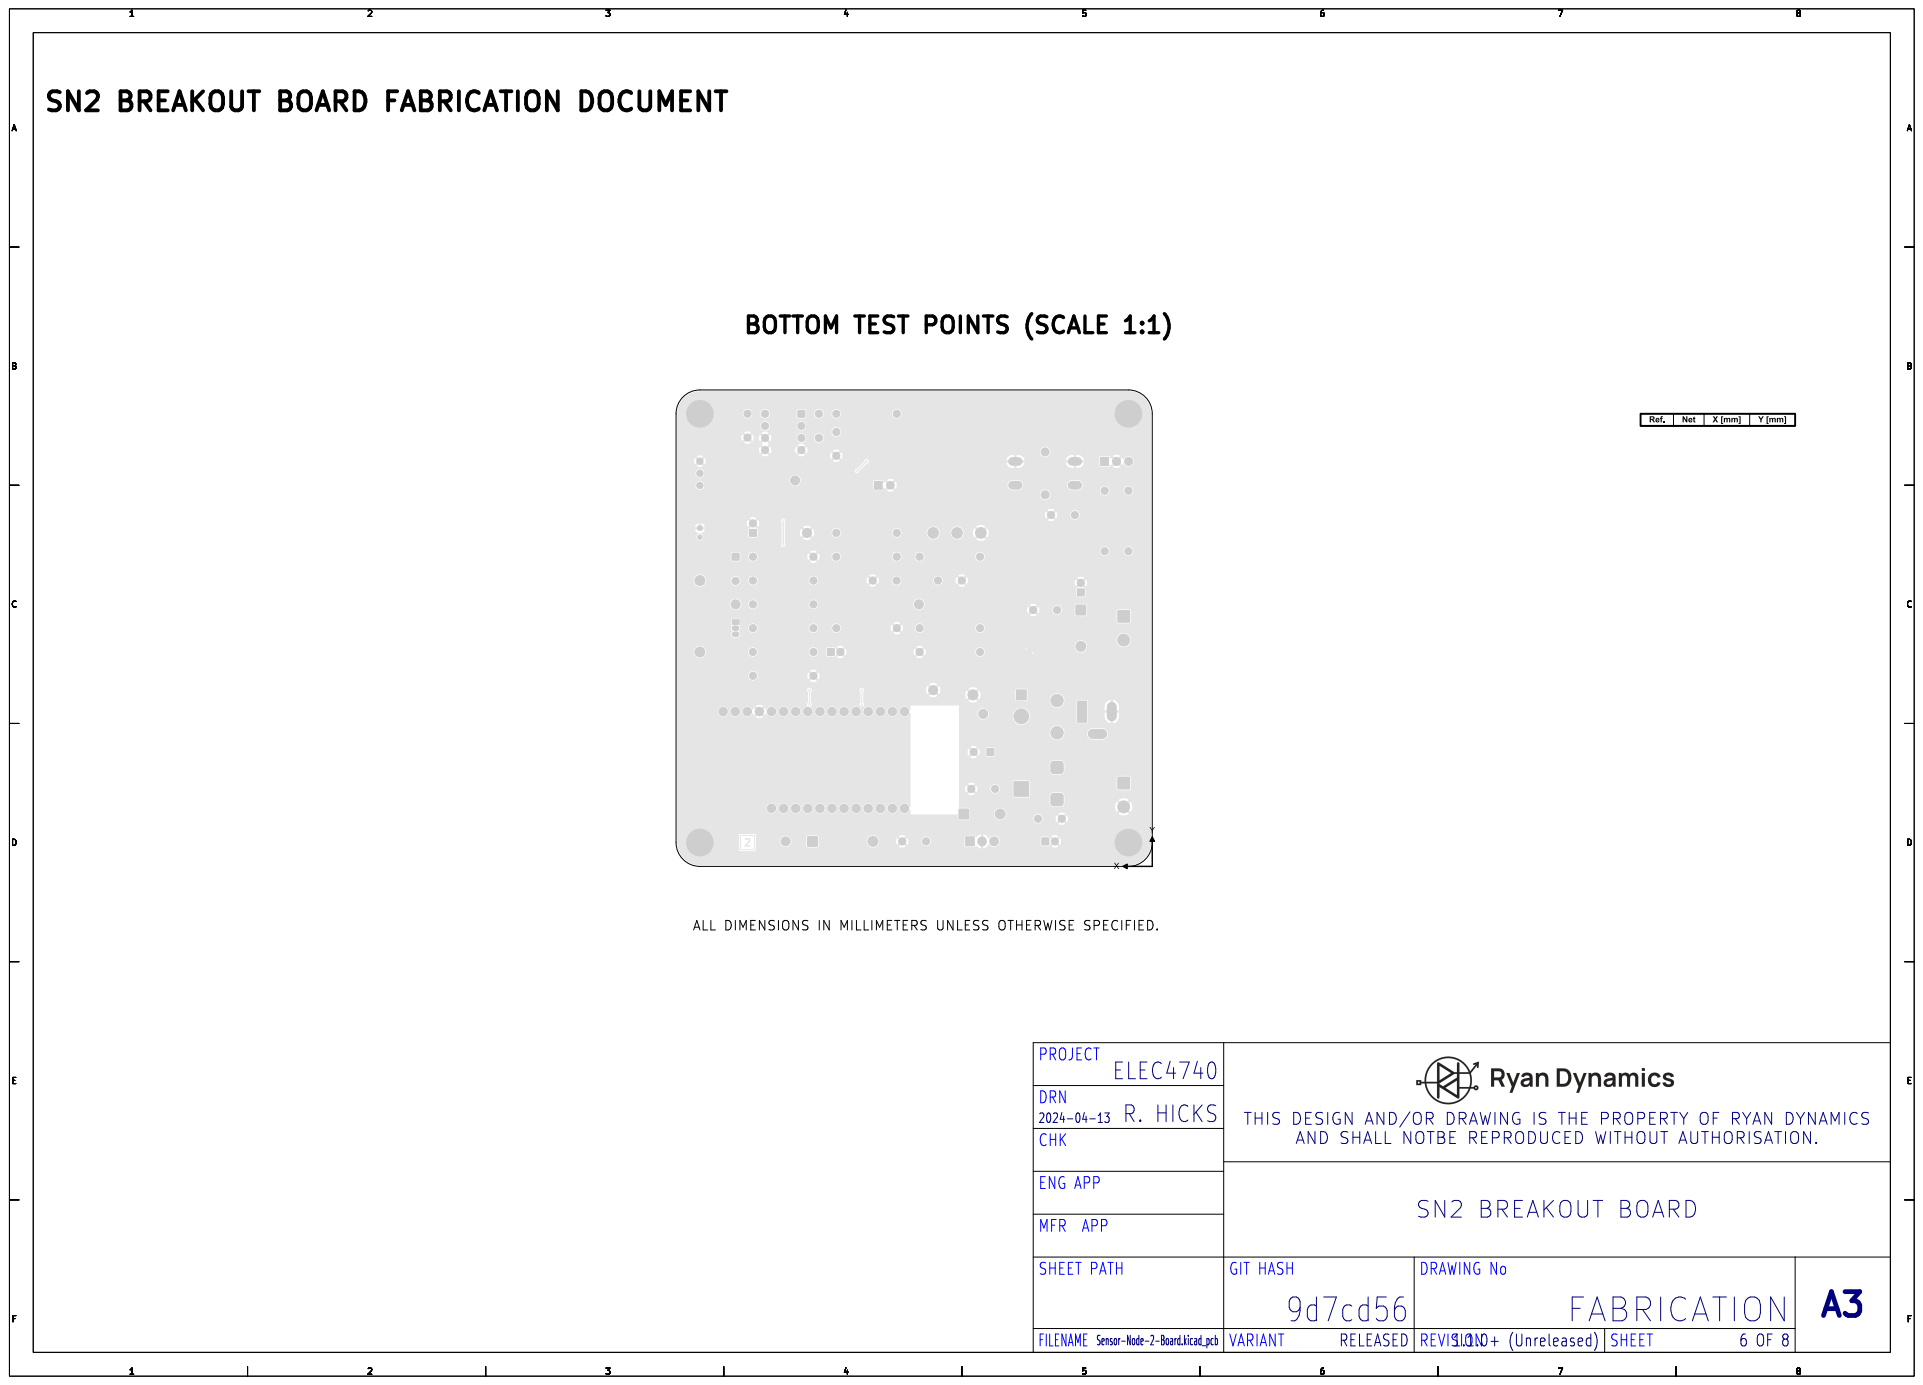
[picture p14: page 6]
DRAWING No; ELEC4740; PROJECT; BREAKOUT; BOARD; ENG APP; GIT; HASH; SHEET; PATH; MFR; APP; R. HICKS; ALL; DIMENSIONS; MILLIMETERS; UNLESS OTHERWISE; SPECIFIED.

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

L1 (Sig, | PWR) (SCALE 1:1)
SN2 BREAKOUT | BOARD FABRICATION | DOCUMENT

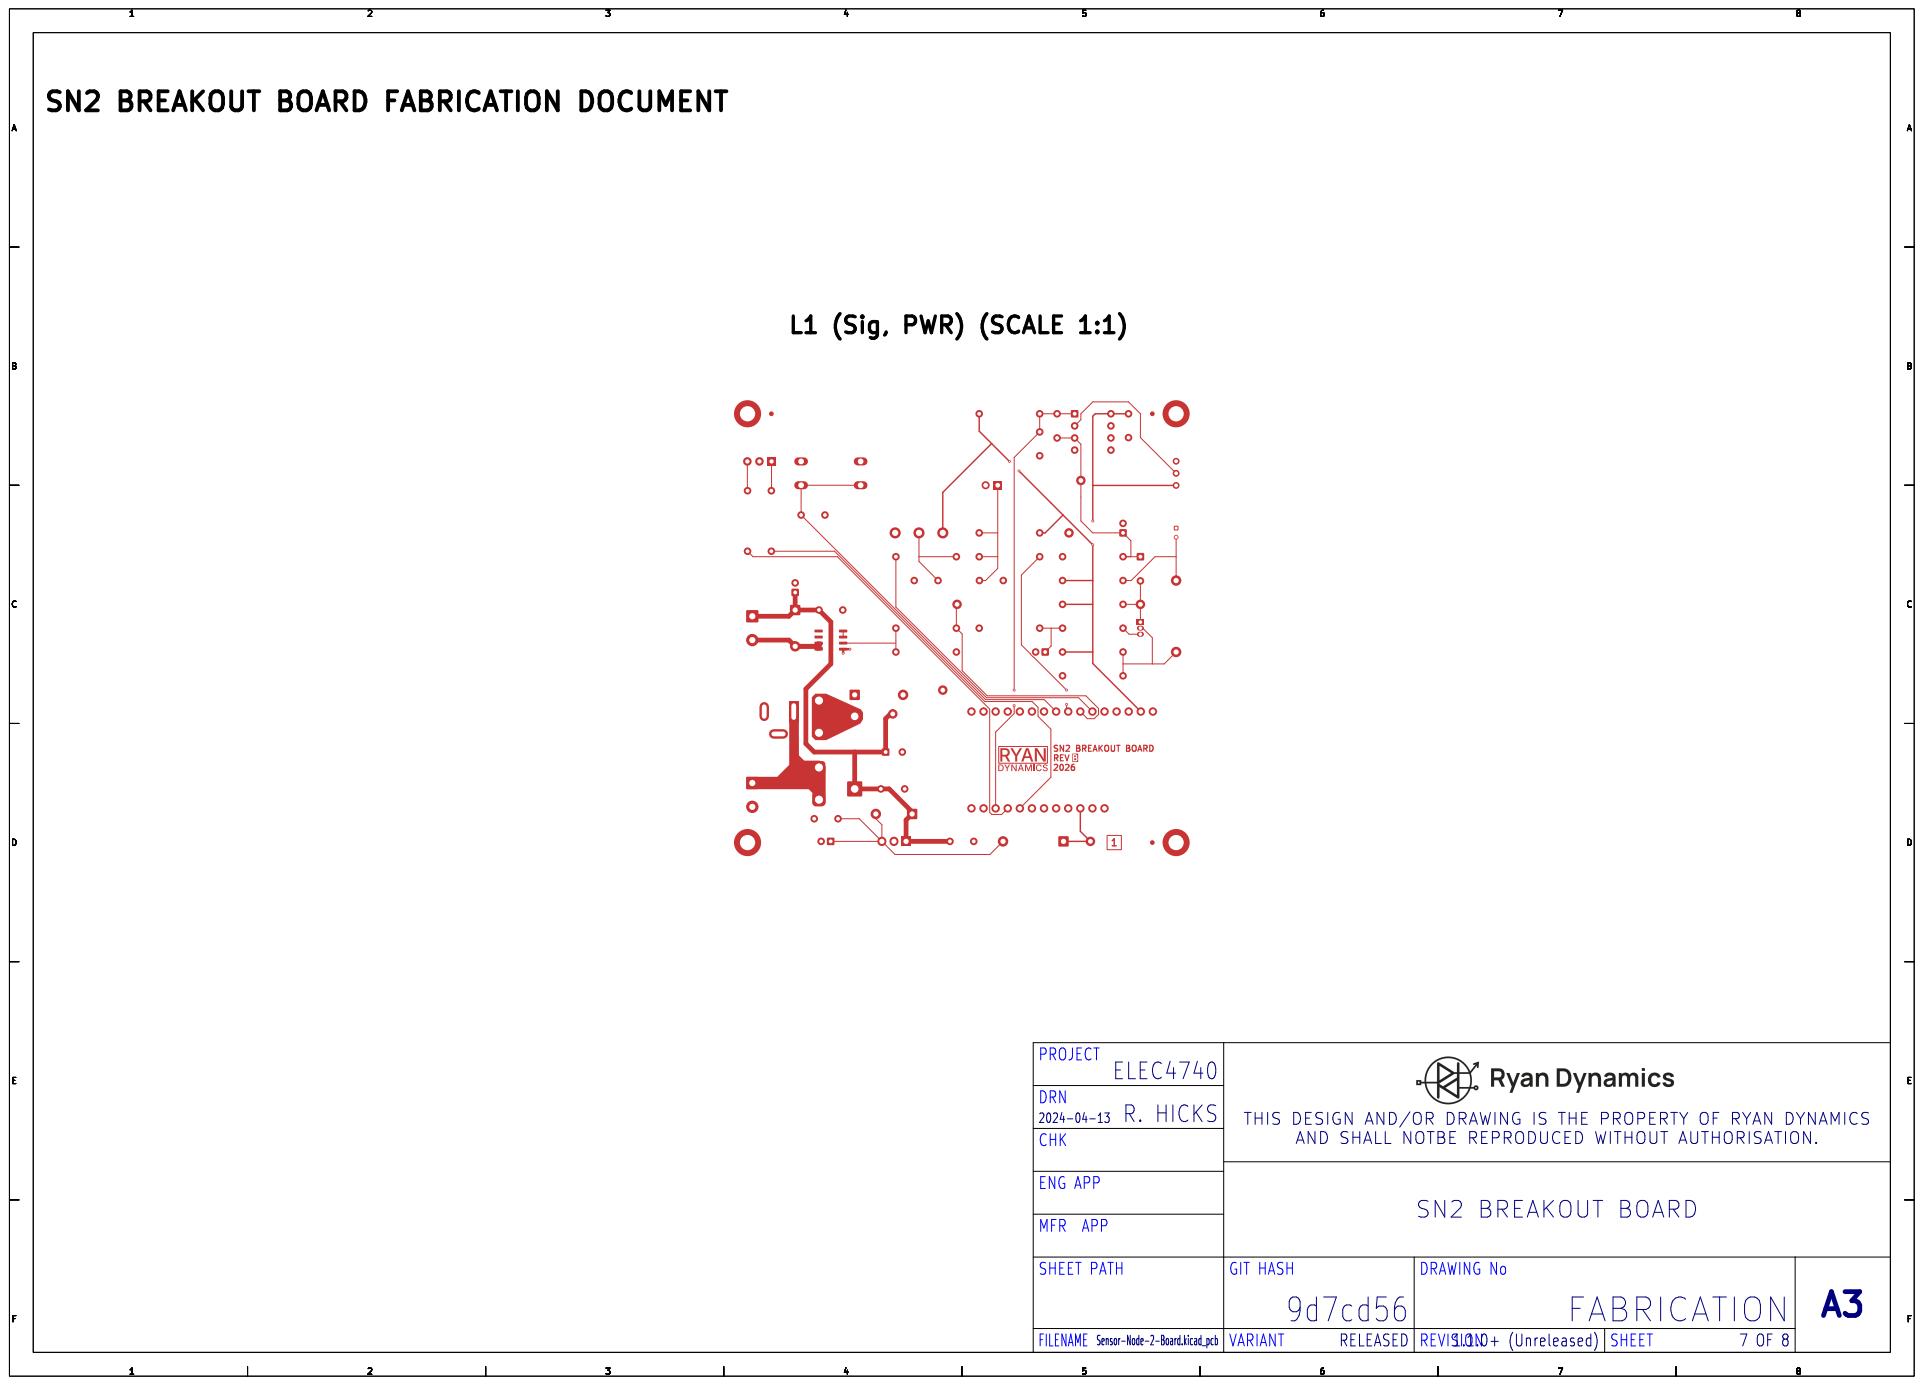
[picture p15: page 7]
DRAWING No; ELEC4740; PROJECT; BREAKOUT; BOARD; ENG APP; 2024-04-13 CHK; GIT; HASH; SHEET; PATH; MFR; APP; DRN; R. HICKS; THIS DESIGN AND/OR; DRAWING IS THE PROPERTY OF RYAN DYNAMICSAND SHALL NOTBE REPRODUCED WITHOUT AUTHORISATION.; REV; SN2 BREAKOUT BOARD

# L2 (Sig, GND) (SCALE 1:1)

SN2 BREAKOUT | BOARD FABRICATION | DOCUMENT

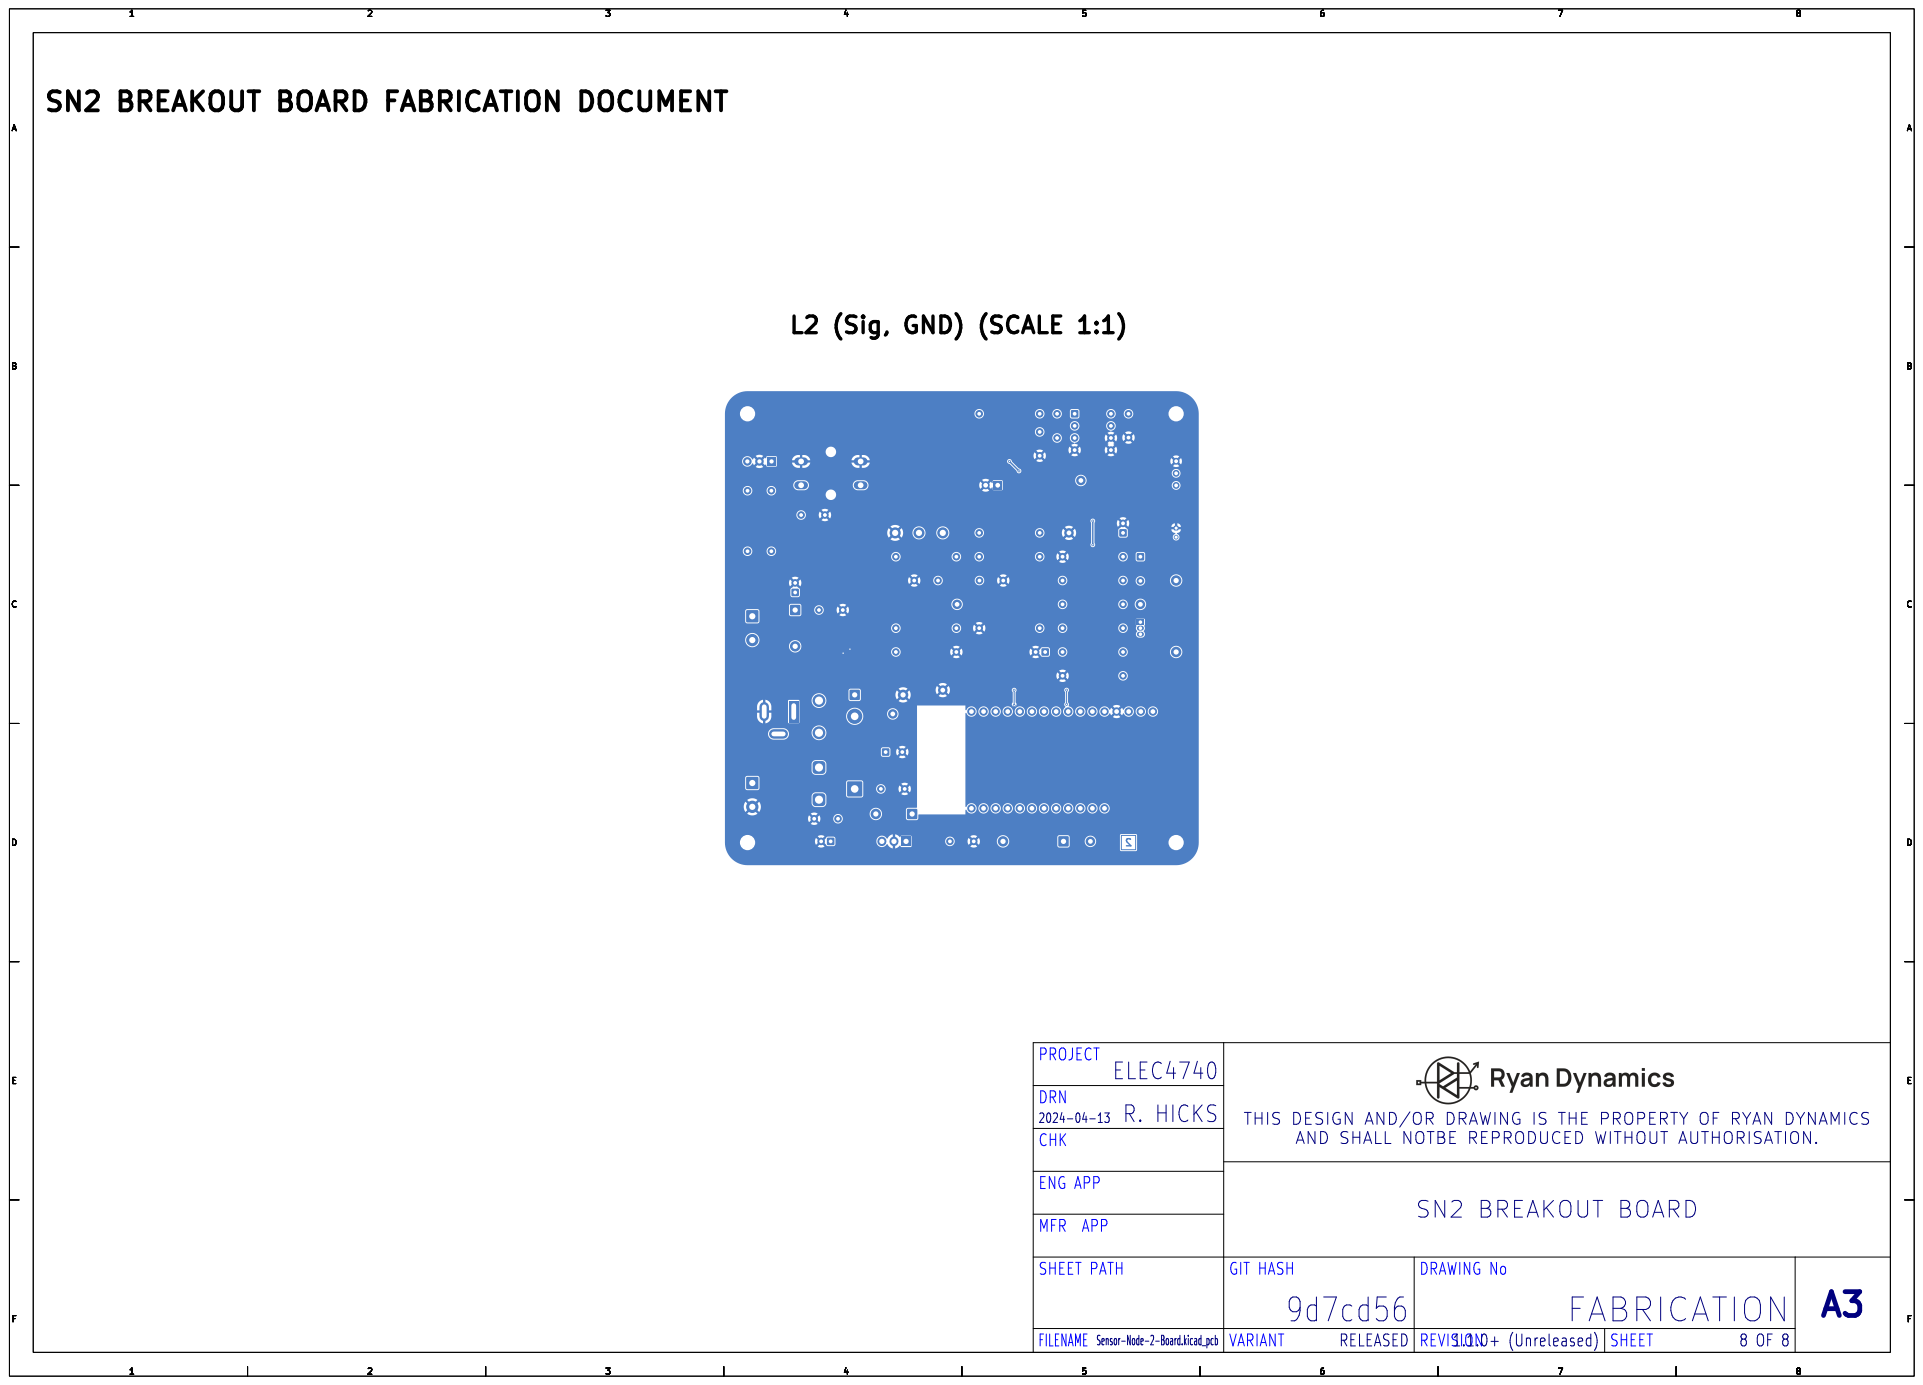
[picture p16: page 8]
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

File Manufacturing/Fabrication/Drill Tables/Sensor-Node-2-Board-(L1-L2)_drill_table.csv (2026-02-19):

Count | Hole Size | Plated | Hole Shape | Drill Layer Pair | Hole Type
10 | 0.30mm (11.81mils) | PTH | Round | L1 (Sig, PWR) - L2 (Sig, GND) | Via
2 | 0.65mm (25.59mils) | PTH | Round | L1 (Sig, PWR) - L2 (Sig, GND) | Pad
3 | 0.75mm (29.53mils) | PTH | Round | L1 (Sig, PWR) - L2 (Sig, GND) | Pad
73 | 0.80mm (31.50mils) | PTH | Round | L1 (Sig, PWR) - L2 (Sig, GND) | Pad
3 | 0.90mm (35.43mils) | PTH | Round | L1 (Sig, PWR) - L2 (Sig, GND) | Pad
37 + 3 | 1.00mm (39.37mils) | PTH | Round + Slot | L1 (Sig, PWR) - L2 (Sig, GND) | Pad
13 | 1.10mm (43.31mils) | PTH | Round | L1 (Sig, PWR) - L2 (Sig, GND) | Pad
4 | 1.20mm (47.24mils) | PTH | Round | L1 (Sig, PWR) - L2 (Sig, GND) | Pad
7 | 1.30mm (51.18mils) | PTH | Round | L1 (Sig, PWR) - L2 (Sig, GND) | Pad
2 | 1.60mm (62.99mils) | PTH | Round | L1 (Sig, PWR) - L2 (Sig, GND) | Pad
4 | 1.70mm (66.93mils) | PTH | Round | L1 (Sig, PWR) - L2 (Sig, GND) | Pad
4 | 3.20mm (125.98mils) | PTH | Round | L1 (Sig, PWR) - L2 (Sig, GND) | Pad
Total 165

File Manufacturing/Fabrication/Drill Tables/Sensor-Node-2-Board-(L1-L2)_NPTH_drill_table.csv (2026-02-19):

Count | Hole Size | Plated | Hole Shape | Drill Layer Pair | Hole Type
2 | 1.80mm (70.87mils) | NPTH | Round | L1 (Sig, PWR) - L2 (Sig, GND) | Mechanical
Total 2

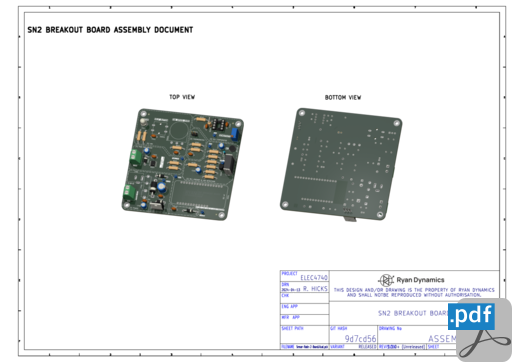
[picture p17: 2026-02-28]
HTML/images/cat_pdf_assembly_Sensor-Node-2-Board-assembly.png

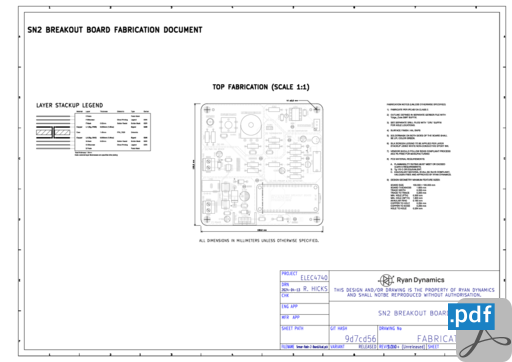
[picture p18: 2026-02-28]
HTML/images/cat_pdf_fabrication_Sensor-Node-2-Board-fabrication.png

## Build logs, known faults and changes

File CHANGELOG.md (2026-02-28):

# Changelog

## [Unreleased]

## [1.1.0] - 2026-02-28

### Changed

-   N/A

### Added

-   N/A

### Removed

-   N/A

### Fixed

-   Wiring of status LED to uC
-   12V power supply protection improved

## [1.0.0] - 2026-02-19

### Changed

-   N/A

### Added

-   Initial release

### Removed

-   N/A

### Fixed

-   N/A

[Unreleased]: https://github.com/Reemuson/ELEC4740-Sensor-Node-2-Board/compare/1.1.0...HEAD

[1.1.0]: https://github.com/Reemuson/ELEC4740-Sensor-Node-2-Board/compare/1.0.0...1.1.0

[1.0.0]: https://github.com/Reemuson/ELEC4740-Sensor-Node-2-Board/compare/9d7cd565d1e090ca3c349ce7d05195f600d042a7...1.0.0

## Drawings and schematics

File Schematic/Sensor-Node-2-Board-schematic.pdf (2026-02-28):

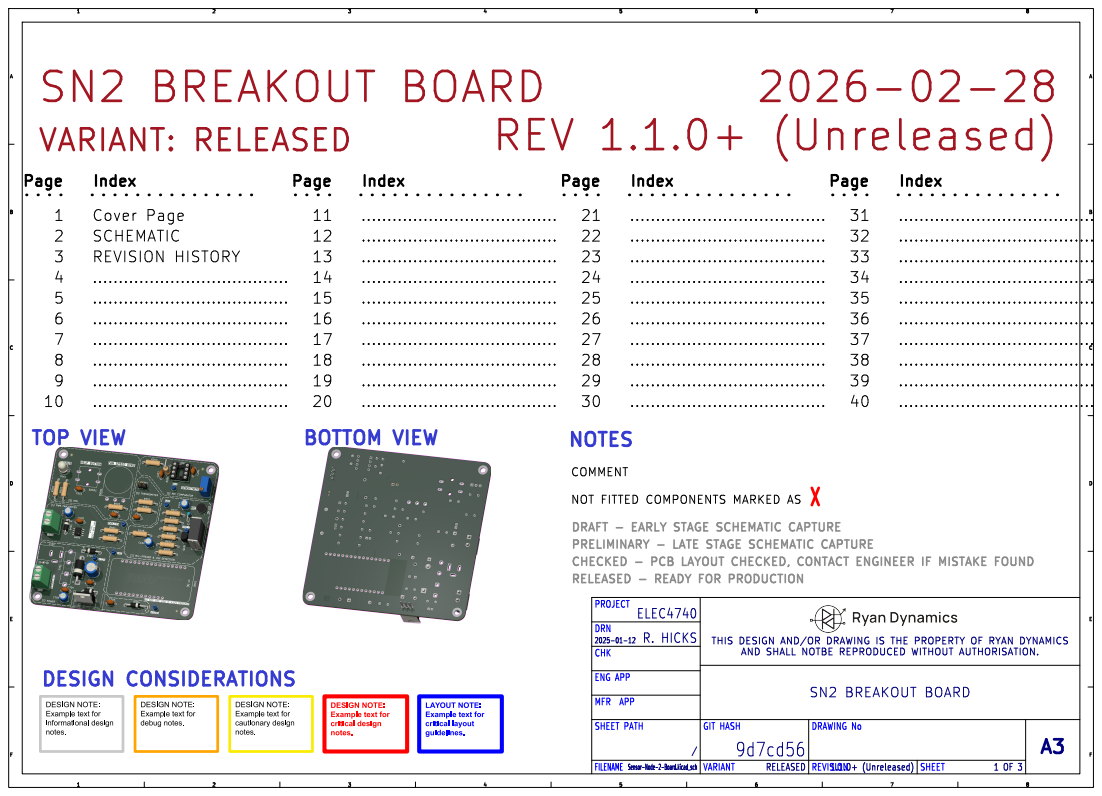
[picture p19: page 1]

NOT FITTED COMPONENTS MARKED AS

DRAFT - EARLY STAGE SCHEMATIC CAPTURE
PRELIMINARY - LATE STAGE SCHEMATIC CAPTURE
CHECKED - PCB LAYOUT CHECKED, CONTACT ENGINEER IF MISTAKE FOUND
RELEASED - READY FOR PRODUCTION

THIS DESIGN AND/OR DRAWING IS THE PROPERTY OF RYAN DYNAMICS

AND SHALL NOTBE REPRODUCED WITHOUT AUTHORISATION.

File: Project Architecture.kicad_sch LAYOUT NOTE:
Example text for
critical layout
guidelines.

FILENAME Sensor-Node-2-Board.kicad_sch

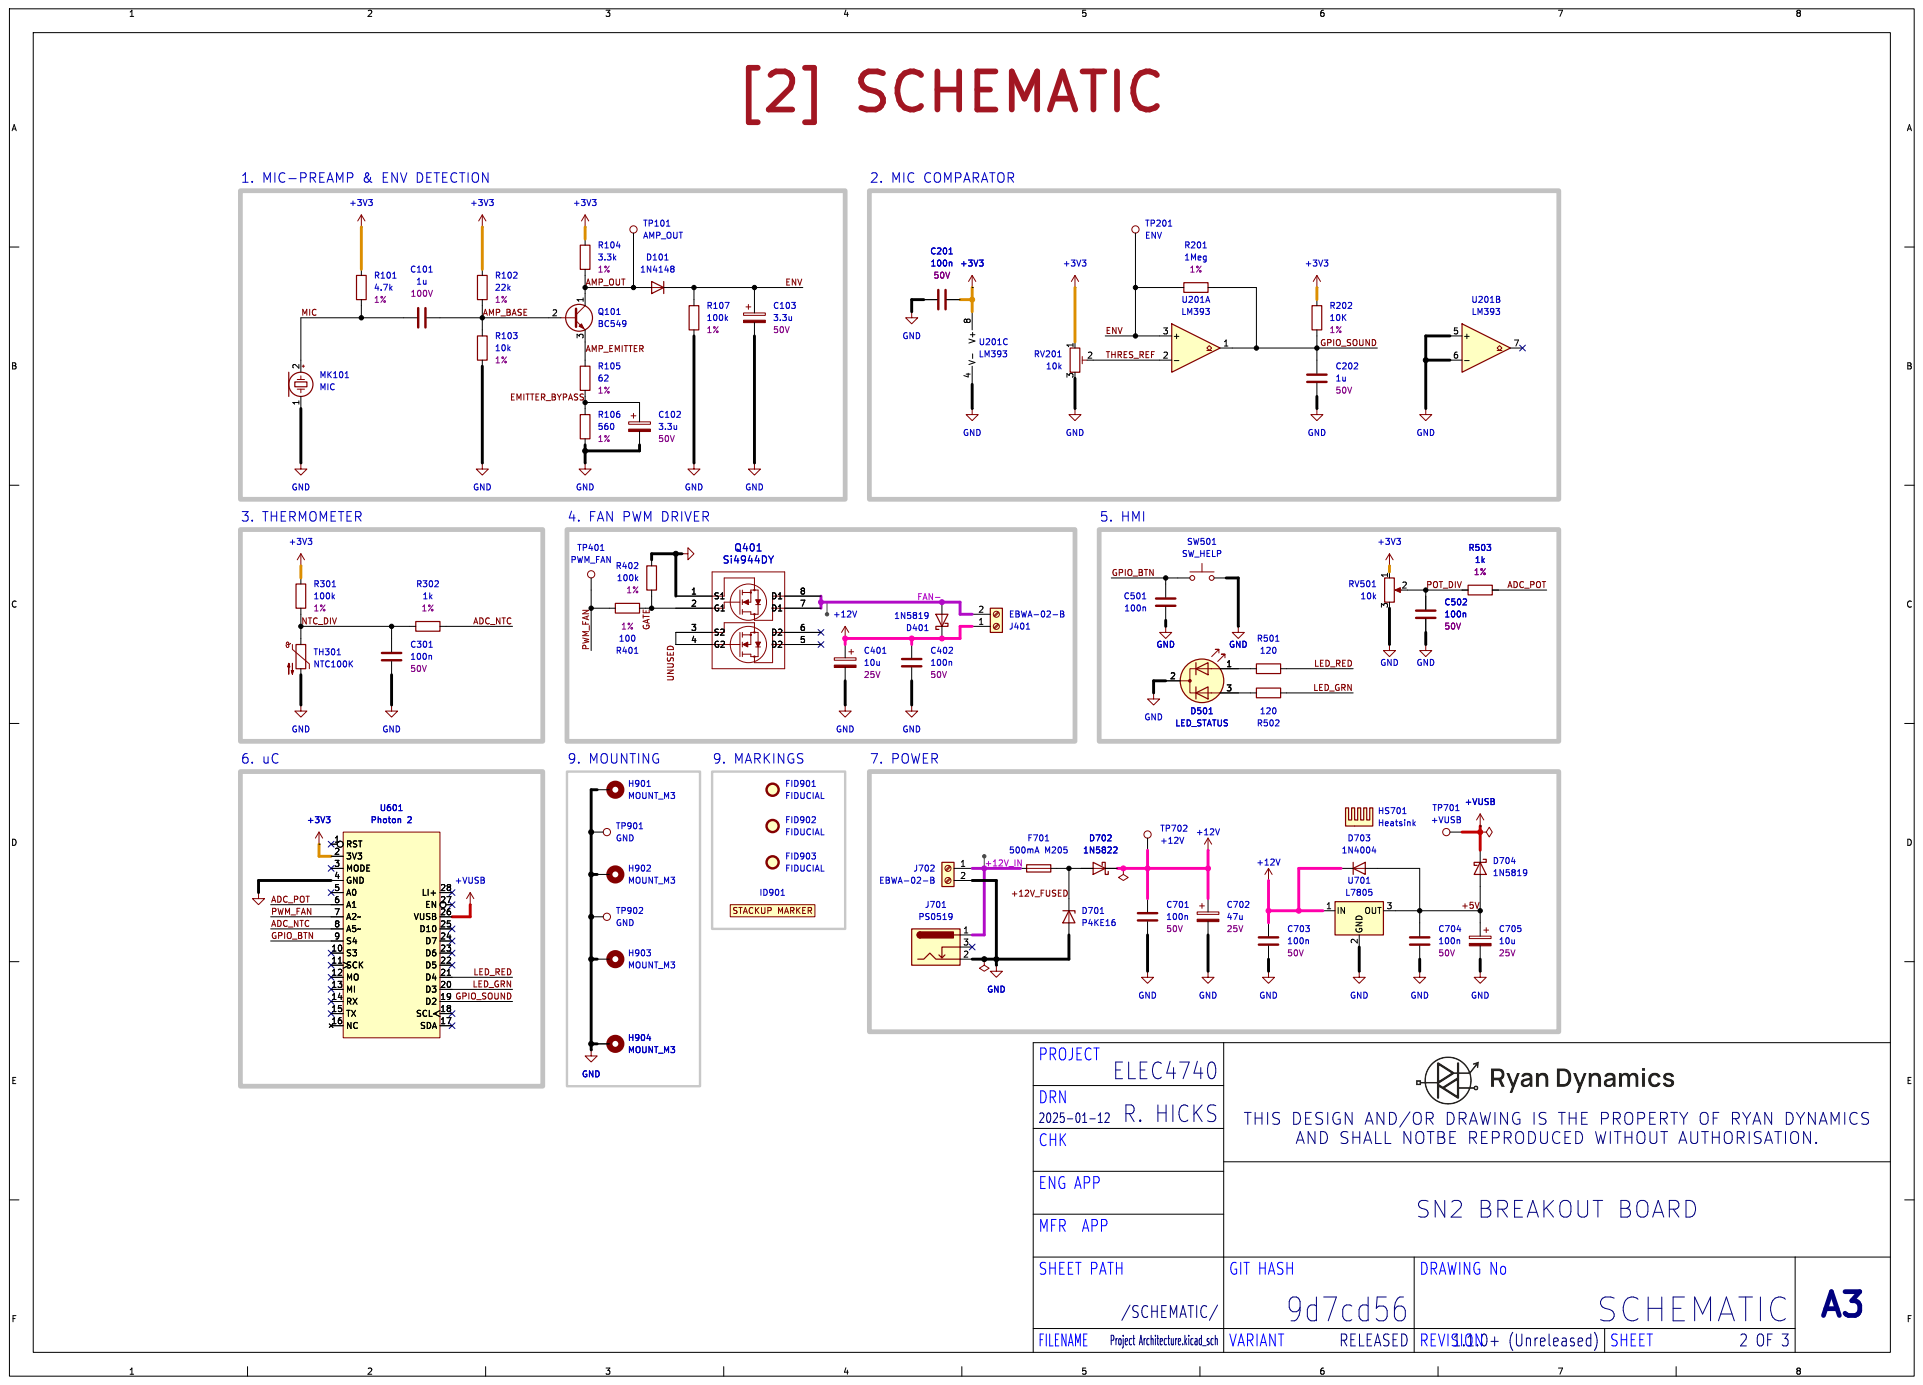
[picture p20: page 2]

1. MIC-PREAMP & ENV DETECTION

25V GND
LI+ 28 EN 27 VUSB 26 D10 25 D7 24 D6 23 D5 22 D4 21 D3 20 D2 19 SCL~ 18 SDA 17 U601 Photon 2
3V3 2 MODE 3 GND 4 A0 5 A1 6 A2~ 7 A5~ 8 S4 9 S3 10 SCK 11 MO 12 MI 13 RX 14 TX 15 NC 16
LI+ 28 EN 27 VUSB 26 D10 25 D7 24 D6 23 D5 22 D4 21 D3 20 D2 19 SCL~ 18 SDA 17

FID903 FIDUCIAL FID901 FIDUCIAL FID902 FIDUCIAL +3V3

THIS DESIGN AND/OR DRAWING IS THE PROPERTY OF RYAN DYNAMICS

AND SHALL NOTBE REPRODUCED WITHOUT AUTHORISATION.

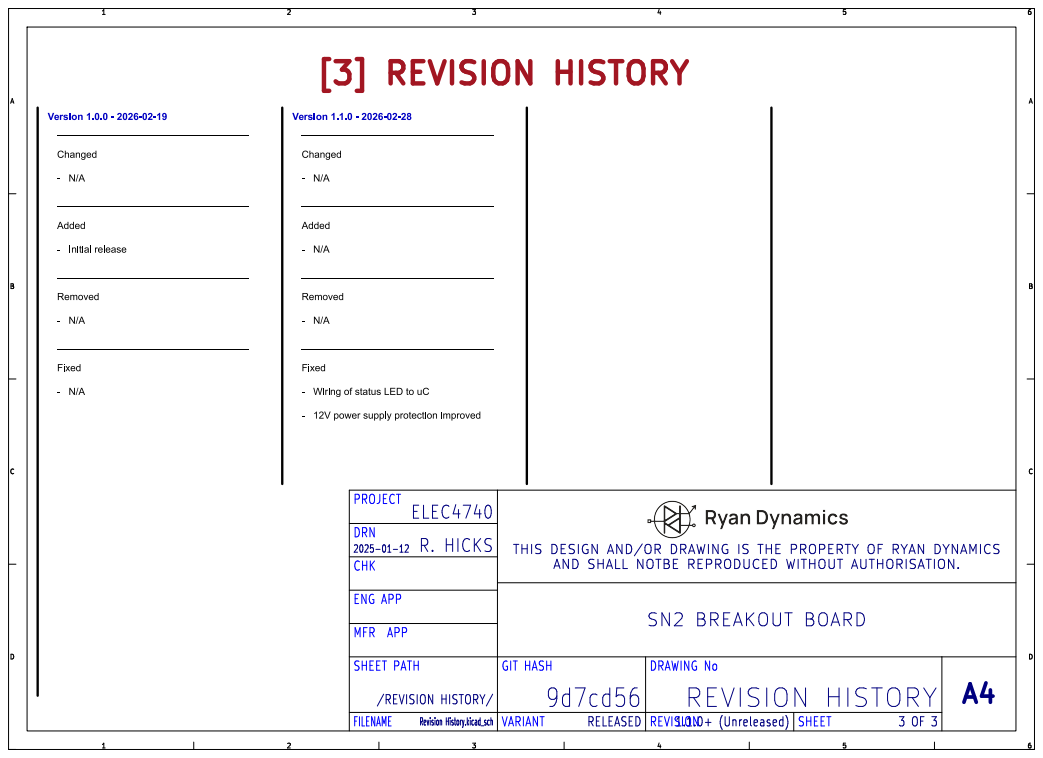
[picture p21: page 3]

- Wiring of status LED to uC

- 12V power supply protection improved

THIS DESIGN AND/OR DRAWING IS THE PROPERTY OF RYAN DYNAMICS

AND SHALL NOTBE REPRODUCED WITHOUT AUTHORISATION.

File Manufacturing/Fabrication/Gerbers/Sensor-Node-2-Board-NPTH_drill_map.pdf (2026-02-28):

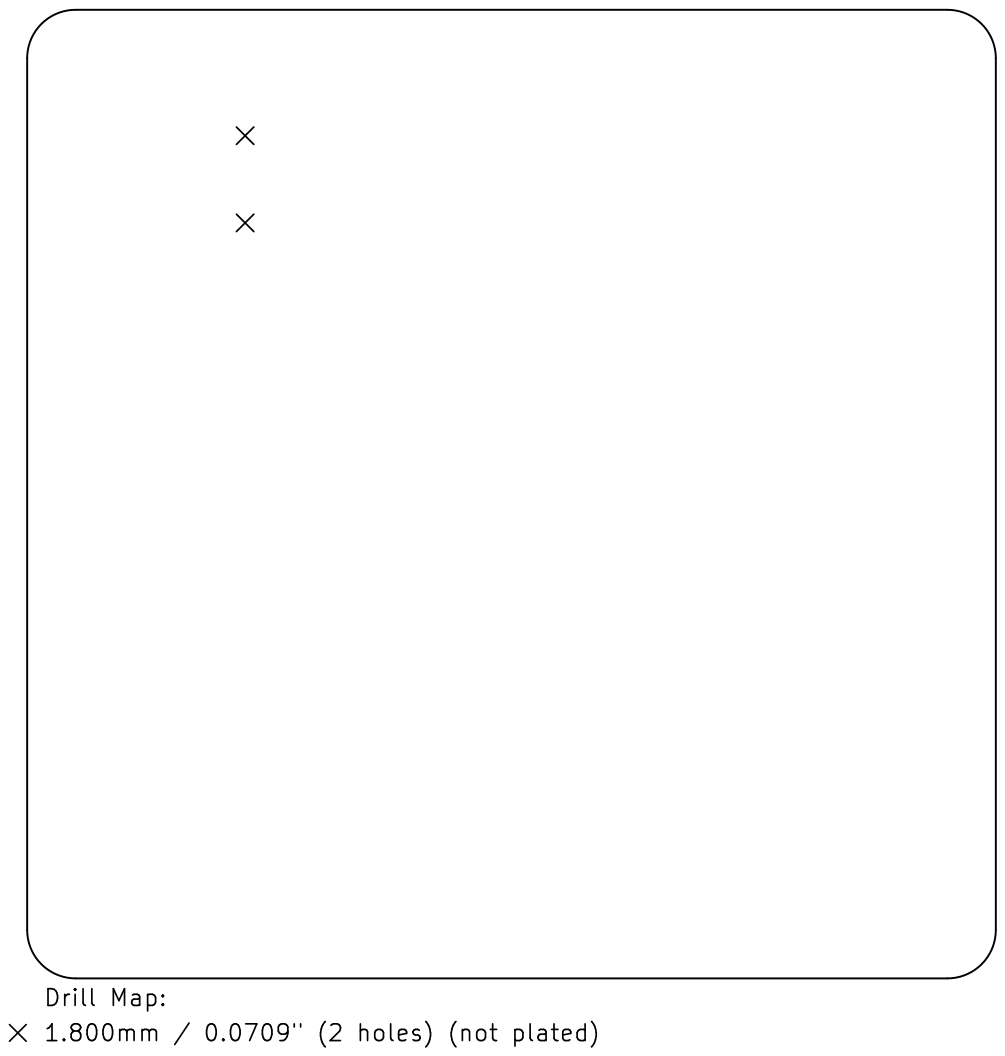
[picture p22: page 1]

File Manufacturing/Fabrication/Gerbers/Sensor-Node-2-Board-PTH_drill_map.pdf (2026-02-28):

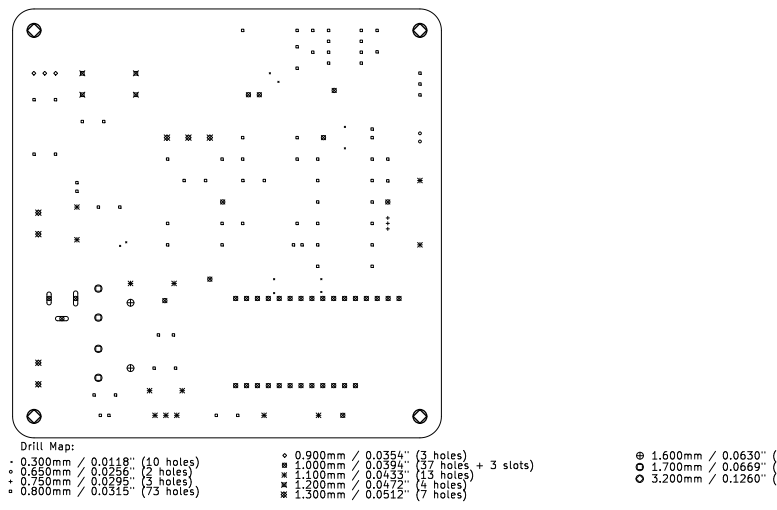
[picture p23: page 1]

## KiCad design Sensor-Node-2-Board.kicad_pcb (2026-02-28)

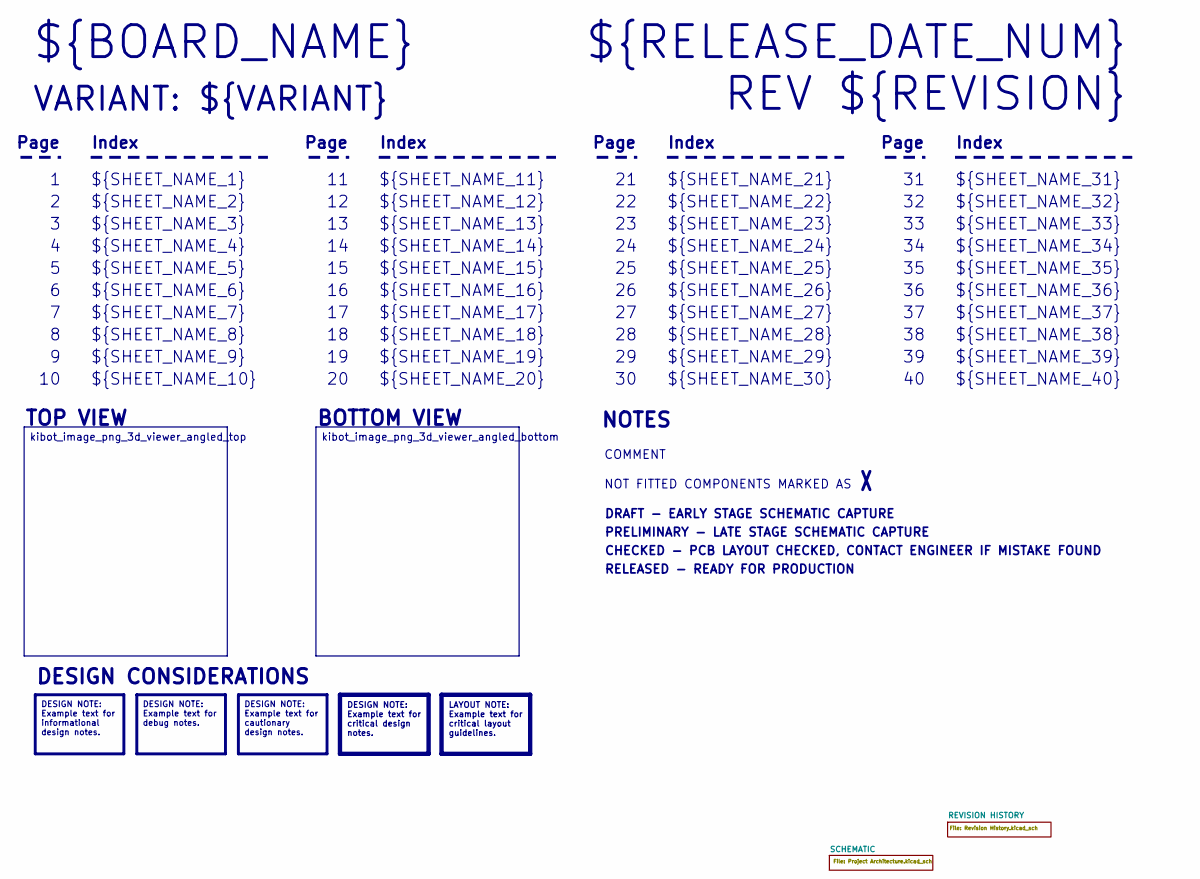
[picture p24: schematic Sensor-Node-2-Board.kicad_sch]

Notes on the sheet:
VARIANT: ${VARIANT}
RELEASED - READY FOR PRODUCTION
${SHEET_NAME_24}
Index
Page
PRELIMINARY - LATE STAGE SCHEMATIC CAPTURE
${SHEET_NAME_22}
DRAFT - EARLY STAGE SCHEMATIC CAPTURE
${SHEET_NAME_12}
${SHEET_NAME_8}
${SHEET_NAME_2}
${SHEET_NAME_5}
${SHEET_NAME_20}
${SHEET_NAME_23}
${RELEASE_DATE_NUM}
${SHEET_NAME_35}
NOT FITTED COMPONENTS MARKED AS
${SHEET_NAME_11}
${SHEET_NAME_6}
${SHEET_NAME_37}
${SHEET_NAME_26}
${SHEET_NAME_36}
REV ${REVISION}
${SHEET_NAME_15}
CHECKED - PCB LAYOUT CHECKED, CONTACT ENGINEER IF MISTAKE FOUND
BOTTOM VIEW
${SHEET_NAME_14}
${SHEET_NAME_21}
${SHEET_NAME_17}
${SHEET_NAME_18}
${SHEET_NAME_7}
${SHEET_NAME_31}
${BOARD_NAME}
NOTES
${SHEET_NAME_40}
${SHEET_NAME_39}
${SHEET_NAME_32}
${SHEET_NAME_1}
${SHEET_NAME_9}
${SHEET_NAME_38}

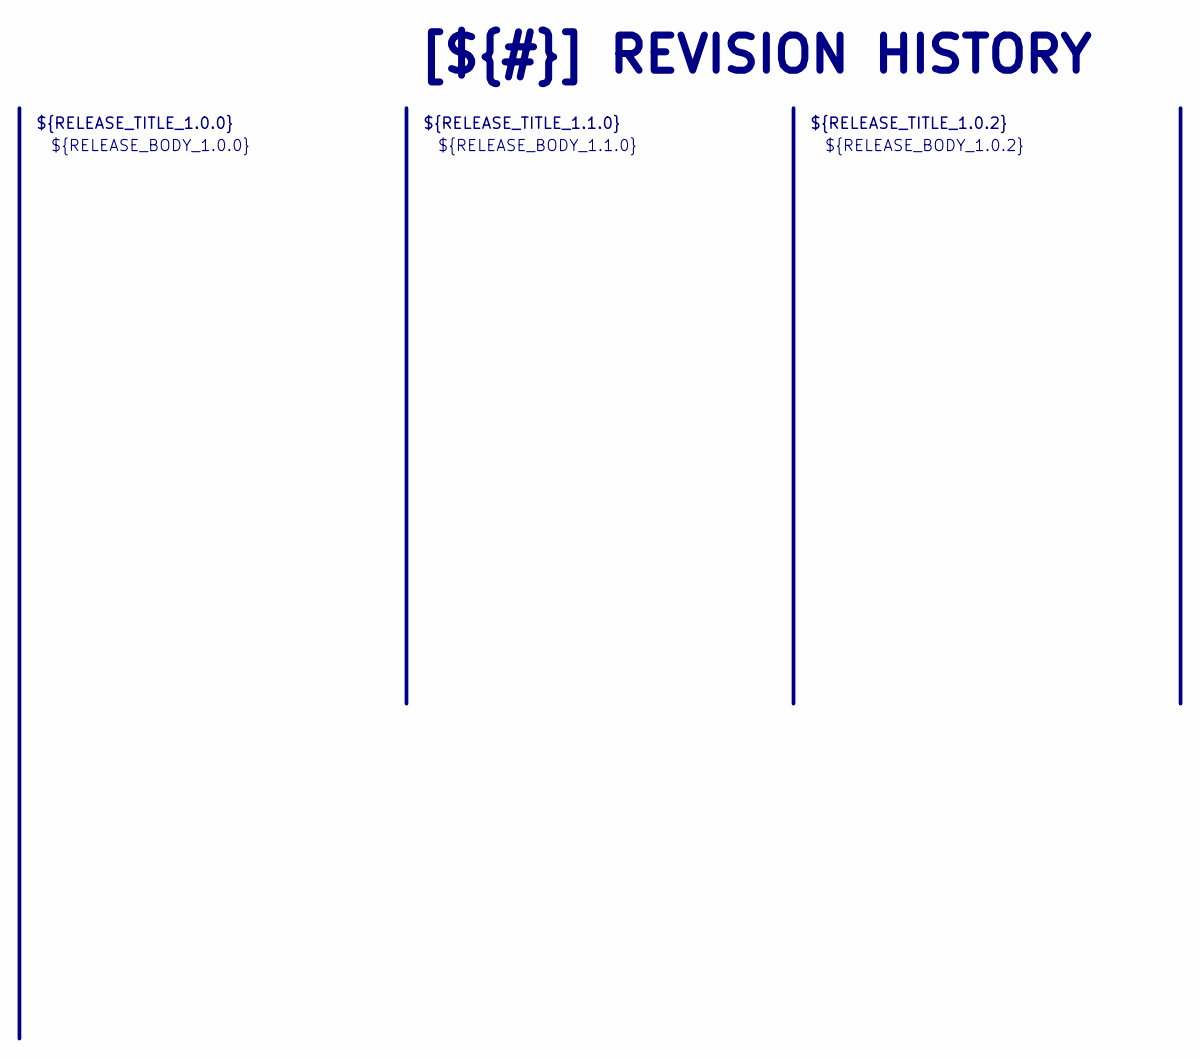
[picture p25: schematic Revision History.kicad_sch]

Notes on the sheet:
[${#}] ${TITLE}
${RELEASE_BODY_1.0.0}
${RELEASE_TITLE_1.0.2}
${RELEASE_BODY_1.0.2}
${RELEASE_BODY_1.1.0}
${RELEASE_TITLE_1.0.0}
${RELEASE_TITLE_1.1.0}

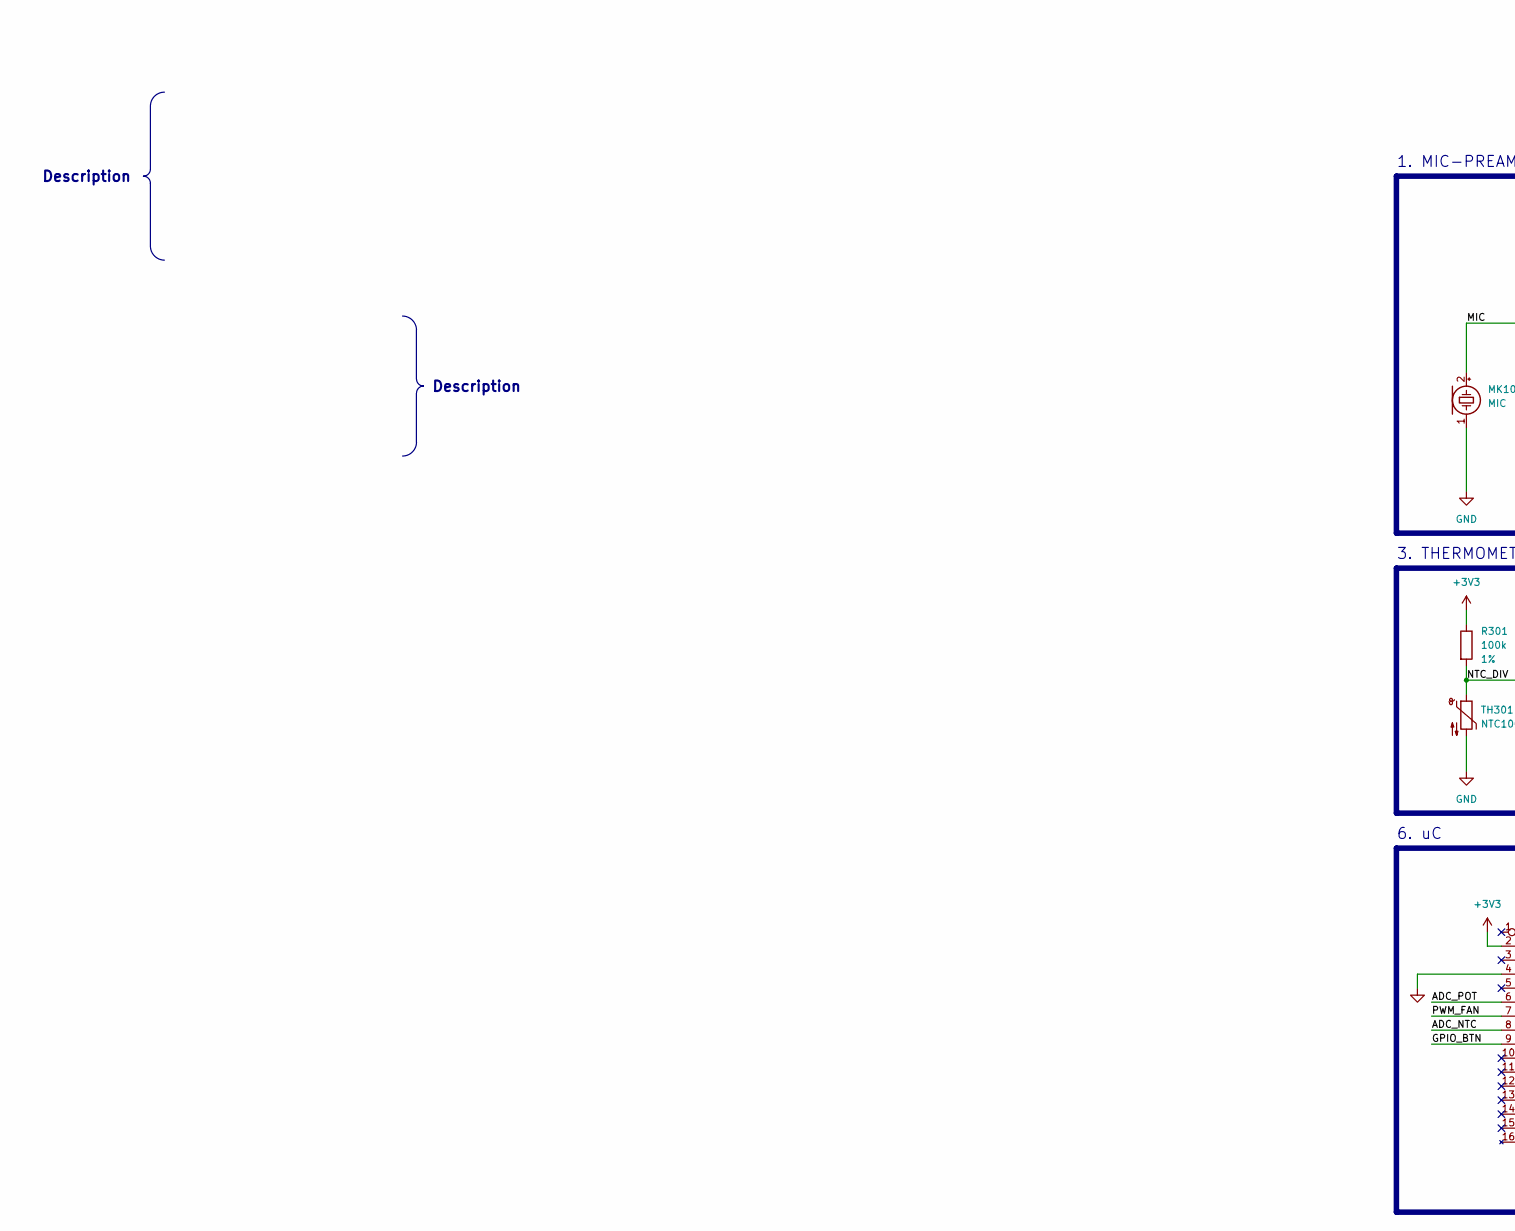
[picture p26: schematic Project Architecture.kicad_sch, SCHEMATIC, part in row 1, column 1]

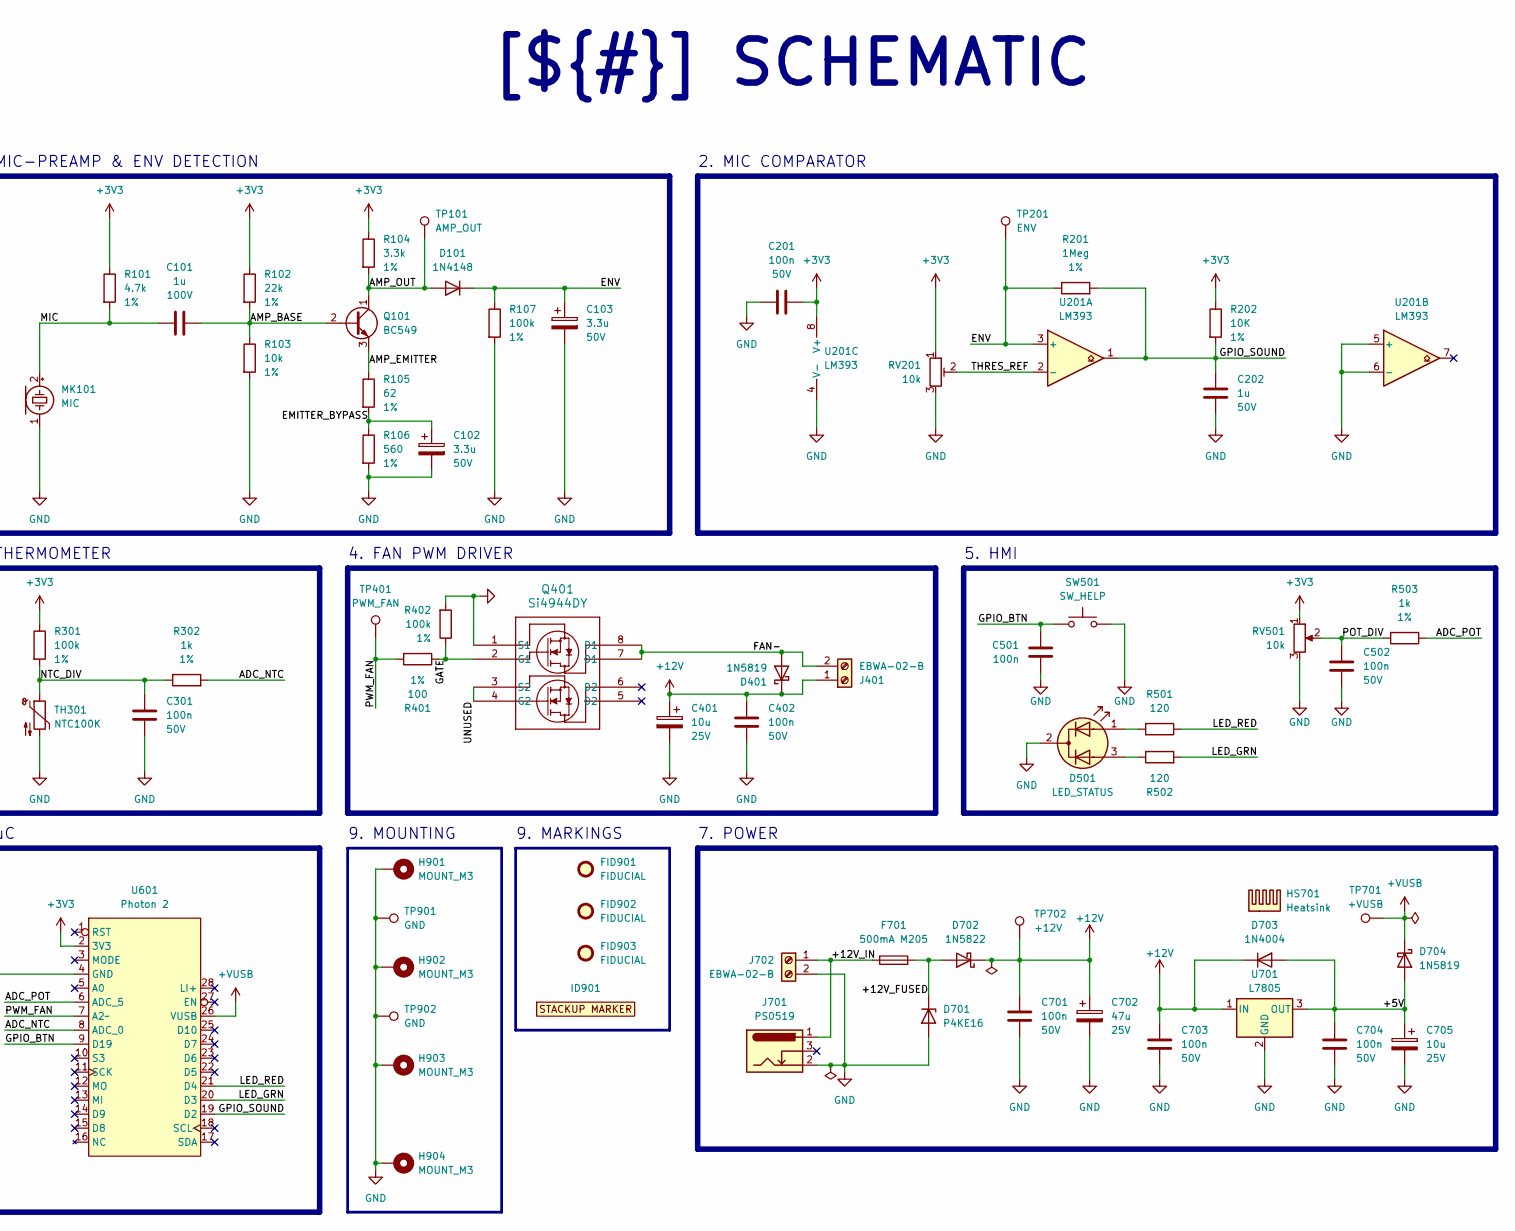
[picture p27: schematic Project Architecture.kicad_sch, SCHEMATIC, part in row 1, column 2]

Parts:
C101: 1u; C_Rect_L16.5mm_W6.0mm_P15.00mm_MKT; Voltage 100V
C102, C103: 3.3u; CP_Radial_D5.0mm_P2.00mm; Voltage 50V; Tolerance 10%
C201, C301, C402, C501, C502, C701, C703, C704: 100n; C_Disc_D5.0mm_W2.5mm_P5.00mm; Tolerance 20%; Voltage 50V
C202: 1u; C_Disc_D5.0mm_W2.5mm_P5.00mm; Voltage 50V
C401, C705: 10u; CP_Radial_D5.0mm_P2.00mm; Voltage 25V
C702: 47u; CP_Radial_D8.0mm_P3.50mm; Voltage 25V
D101: 1N4148; D_DO-35_SOD27_P5.08mm_Vertical_AnodeUp
D401: 1N5819; D_DO-41_SOD81_P7.62mm_Horizontal
D501: LED_STATUS; LED_D5.0mm-3
D701: P4KE16; D_DO-41_SOD81_P10.16mm_Horizontal
D702: 1N5822; D_DO-201AD_P15.24mm_Horizontal
D703: 1N4004; D_DO-41_SOD81_P7.62mm_Horizontal
D704: 1N5819; D_DO-41_SOD81_P12.70mm_Horizontal
F701: 500mA M205; Fuseholder_Clip-5x20mm_Eaton_1A5601-01_Inline_P20.80x6.76mm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
FID901, FID902, FID903: FIDUCIAL; Fiducial_1mm_Mask2mm
H901, H902, H903, H904: MOUNT_M3; MountingHole_3.2mm_M3_ISO7380_Pad
HS701: Heatsink; Heatsink_6073B_19x9.5mm
ID901: BOARD_STACKUP_MARKER; STACKUP_ID_2L
J401, J702: EBWA-02-B; TerminalBlock_Phoenix_MKDS-1,5-2_1x02_P5.00mm_Horizontal
J701: PS0519; BarrelJack_Kycon_KLDX-0202-xC_Horizontal
MK101: MIC; POM-2244P-C3310-2-R
Q101: BC549; TO-92_Inline
Q401: Si4944DY; SO-8_3.9x4.9mm_P1.27mm
R101: 4.7k; R_Axial_DIN0309_L9.0mm_D3.2mm_P12.70mm_Horizontal; Tolerance 1%
R102: 22k; R_Axial_DIN0309_L9.0mm_D3.2mm_P12.70mm_Horizontal; Tolerance 1%
R103: 10k; R_Axial_DIN0309_L9.0mm_D3.2mm_P12.70mm_Horizontal; Tolerance 1%
R104: 3.3k; R_Axial_DIN0309_L9.0mm_D3.2mm_P12.70mm_Horizontal; Tolerance 1%
R105: 62; R_Axial_DIN0309_L9.0mm_D3.2mm_P12.70mm_Horizontal; Tolerance 1%
R106: 560; R_Axial_DIN0309_L9.0mm_D3.2mm_P12.70mm_Horizontal; Tolerance 1%
R107, R301, R402: 100k; R_Axial_DIN0309_L9.0mm_D3.2mm_P12.70mm_Horizontal; Tolerance 1%
R201: 1Meg; R_Axial_DIN0309_L9.0mm_D3.2mm_P5.08mm_Vertical; Tolerance 1%
R202: 10K; R_Axial_DIN0309_L9.0mm_D3.2mm_P12.70mm_Horizontal; Tolerance 1%
R302, R503: 1k; R_Axial_DIN0309_L9.0mm_D3.2mm_P12.70mm_Horizontal; Tolerance 1%
R401: 100; R_Axial_DIN0309_L9.0mm_D3.2mm_P12.70mm_Horizontal; Tolerance 1%
R501, R502: 120; R_Axial_DIN0309_L9.0mm_D3.2mm_P12.70mm_Horizontal; Tolerance 1%
RV201: 10k; Potentiometer_Bourns_3296W_Vertical
RV501: 10k; Potentiometer_Omeg_PC16BU_Vertical
SW501: SW_HELP; SW_SPST_Omron_B3F-40xx
TH301: NTC100K; PinHeader_1x02_P2.54mm_Vertical
TP101: AMP_OUT; TestPoint_Loop_D1.80mm_Drill1.0mm_Beaded
TP201: ENV; TestPoint_Loop_D1.80mm_Drill1.0mm_Beaded
TP401: PWM_FAN; TestPoint_Loop_D1.80mm_Drill1.0mm_Beaded
TP701: +VUSB; TestPoint_Loop_D1.80mm_Drill1.0mm_Beaded
TP702: +12V; TestPoint_Loop_D1.80mm_Drill1.0mm_Beaded
TP901, TP902: GND; TestPoint_Loop_D1.80mm_Drill1.0mm_Beaded
U201: LM393; DIP-8_W7.62mm_Socket
U601: Photon 2; PHOTON2
U701: L7805; TO-220-3_Vertical

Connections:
+3V3: C201.1, R101.1, R102.1, R104.1, R202.1, R301.1, RV201.1, RV501.1, U201.8 (V+), U601.2 (3V3)
+12V: C401.1, C402.1, C701.2, C702.1, C703.2, D401.1 (K), D702.1 (K), D703.1 (K), J401.1, TP702.1, U701.1 (IN)
+VUSB: D704.1 (K), TP701.1, U601.26 (VUSB)
/SCHEMATIC/+5V: C704.2, C705.1, D703.2 (A), D704.2 (A), U701.3 (OUT)
/SCHEMATIC/+12V_FUSED: D701.1 (K), D702.2 (A), F701.2
/SCHEMATIC/+12V_IN: F701.1, J701.1, J702.1
/SCHEMATIC/ADC_NTC: R302.2, U601.8 (ADC_0)
/SCHEMATIC/ADC_POT: R503.1, U601.6 (ADC_5)
/SCHEMATIC/AMP_BASE: C101.2, Q101.2 (B), R102.2, R103.1
/SCHEMATIC/AMP_EMITTER: Q101.3 (E), R105.1
/SCHEMATIC/AMP_OUT: D101.2 (A), Q101.1 (C), R104.2, TP101.1
/SCHEMATIC/EMITTER_BYPASS: C102.1, R105.2, R106.1
/SCHEMATIC/ENV: C103.1, D101.1 (K), R107.1, R201.1, TP201.1, U201.3 (+)
/SCHEMATIC/FAN-: D401.2 (A), J401.2, Q401.7 (D1), Q401.8 (D1)
/SCHEMATIC/GATE: Q401.2 (G1), R401.1, R402.1
/SCHEMATIC/GPIO_BTN: C501.1, SW501.1, U601.9 (D19)
/SCHEMATIC/GPIO_SOUND: C202.1, R201.2, R202.2, U201.1, U601.19 (D2)
/SCHEMATIC/LED_GRN: R502.2, U601.20 (D3)
/SCHEMATIC/LED_RED: R501.1, U601.21 (D4)
/SCHEMATIC/MIC: C101.1, MK101.2 (+), R101.2
/SCHEMATIC/NTC_DIV: C301.1, R301.2, R302.1, TH301.1
/SCHEMATIC/POT_DIV: C502.2, R503.2, RV501.2
/SCHEMATIC/PWM_FAN: R401.2, TP401.1, U601.7 (A2~)
/SCHEMATIC/THRES_REF: RV201.2, U201.2 (-)
/SCHEMATIC/UNUSED: Q401.3 (S2), Q401.4 (G2)
GND: C102.2, C103.2, C201.2, C202.2, C301.2, C401.2, C402.2, C501.2, C502.1, C701.1, C702.2, C703.1, C704.1, C705.2, D501.2 (K), D701.2 (A), H901.1, H902.1, H903.1, H904.1, J701.2, J702.2, MK101.1 (-), Q401.1 (S1), R103.2, R106.2, R107.2, R402.2, RV201.3, RV501.3, SW501.2, TH301.2, TP901.1, TP902.1, U201.4 (V-), U201.5 (+), U201.6 (-), U601.4 (GND), U701.2 (GND)
unnamed: D501.1 (A1), R501.2
unnamed: D501.3 (A2), R502.1

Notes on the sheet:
6. uC
9. MARKINGS
2. MIC COMPARATOR
9. MOUNTING
3. THERMOMETER
7. POWER
5. HMI
4. FAN PWM DRIVER
1. MIC-PREAMP & ENV DETECTION
Description
[${#}] ${TITLE}

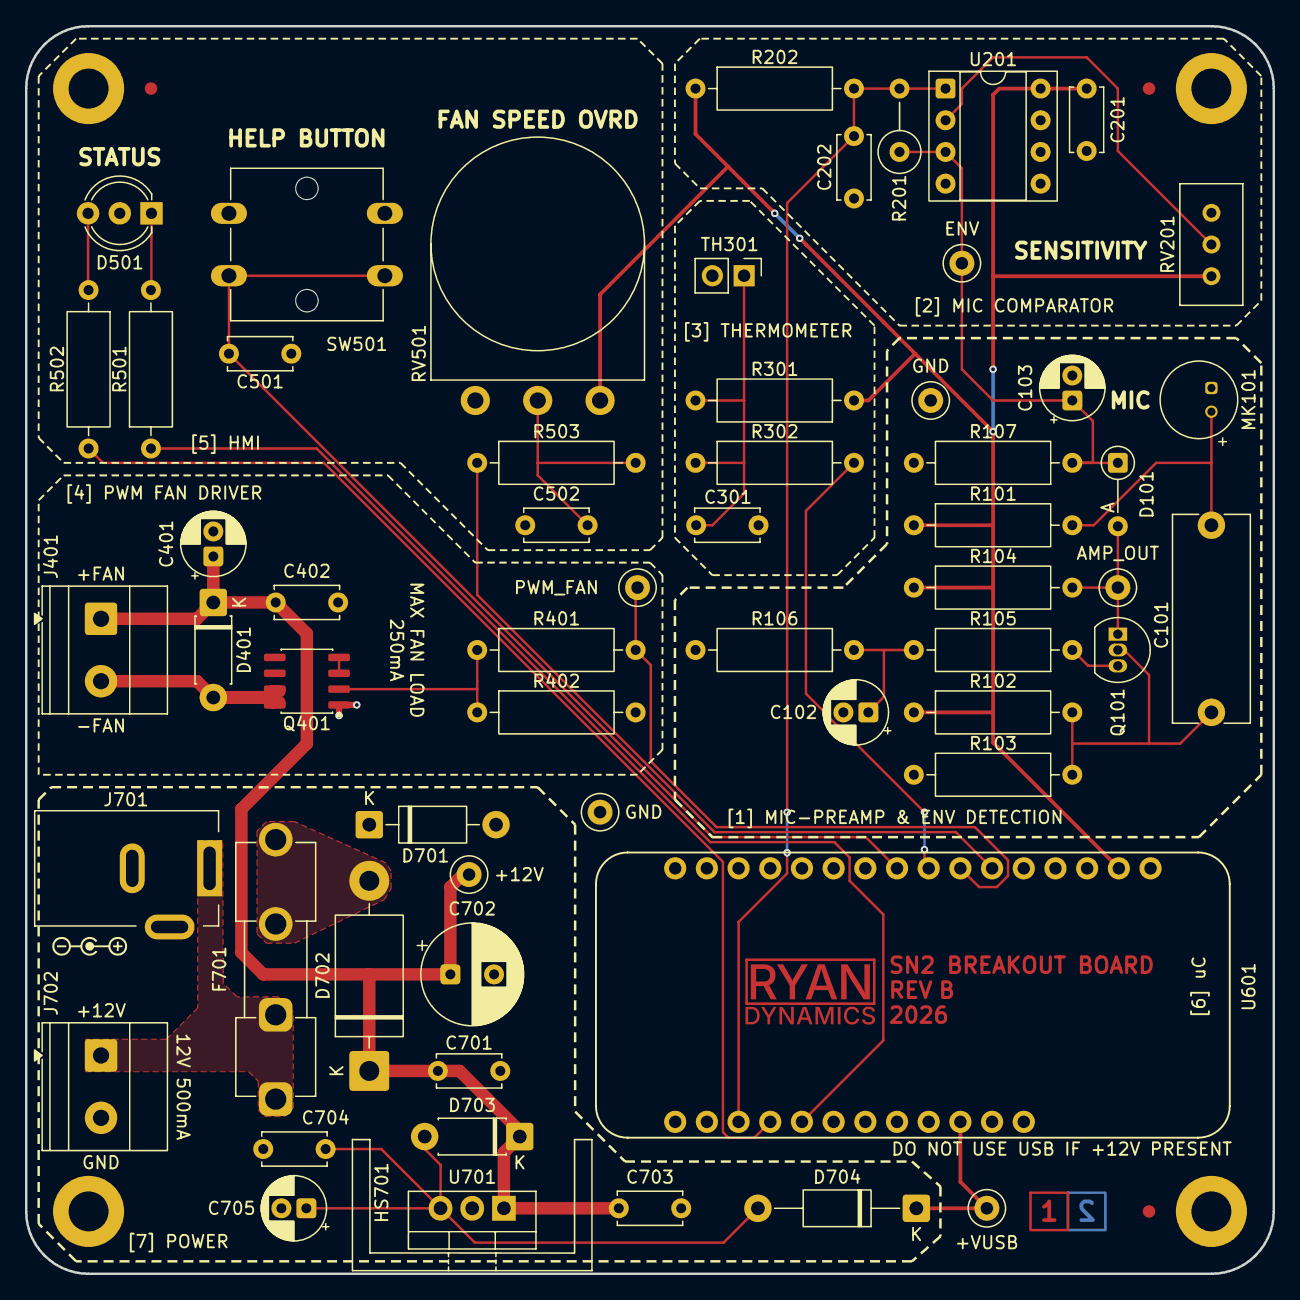
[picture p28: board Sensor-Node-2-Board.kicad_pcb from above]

Board: 2 copper layers, 100.0 x 100.0 mm, 68 parts (0 on the bottom side), 28 nets.

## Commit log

2026-02-19 feat: initial commit
    [Block Diagram.kicad_sch, Project Architecture.kicad_sch, Revision History.kicad_sch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]
2026-02-19 Update Outputs
    [Sensor-Node-2-Board-(L1-L2)_NPTH_drill_table.csv, Sensor-Node-2-Board-(L1-L2)_drill_table.csv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]
2026-02-19 fix: pcb dimensioning
    [Sensor-Node-2-Board.kicad_pcb]
2026-02-19 fix: pcb fab/assembly doc layout
    [Sensor-Node-2-Board.kicad_pcb]
2026-02-19 fix: force pcb outs to A3
    [Sensor-Node-2-Board.kicad_pcb]
2026-02-19 feat: release
    [Project Architecture.kicad_sch, Sensor-Node-2-Board.kicad_pcb]
2026-02-19 Update Outputs (release)
    [Sensor-Node-2-Board-B_Mask.gbr, Sensor-Node-2-Board-B_Paste.gbr, Sensor-Node-2-Board-B_Silkscreen.gbr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]
2026-02-28 fix: change status led wiring and improve 12V input protection
    [Project Architecture.kicad_sch, Revision History.kicad_sch, Sensor-Node-2-Board.kicad_pcb]
2026-02-28 fix: rename board_REV-A.jpg to board-REV-A.jpg
